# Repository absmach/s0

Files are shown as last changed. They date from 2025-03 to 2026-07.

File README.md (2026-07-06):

# 🔌 A0 Gateway

a0 is a modular **IoT gateway** built around the **ESP32-C6 (RISC-V)** platform, offering advanced wireless capabilities such as **Wi-Fi 6**, **Bluetooth 5**, and **802.15.4**. It supports multiple connectivity options including **NB-IoT/LTE-M** and optional **Ethernet**, enabling secure and scalable IoT deployments across **smart buildings**, **industrial environments**, and **city infrastructure**.

Optimized for **low-power, battery-powered operation** and modular expansion, A0 integrates **secure communication**, **local storage**, and multiple radio interfaces to serve as a versatile edge gateway in modern **IoT ecosystems**. While it includes support for **Wireless and Wired M-Bus**, its primary focus is on broad **IoT connectivity** and **interoperability**.

<p align="center">
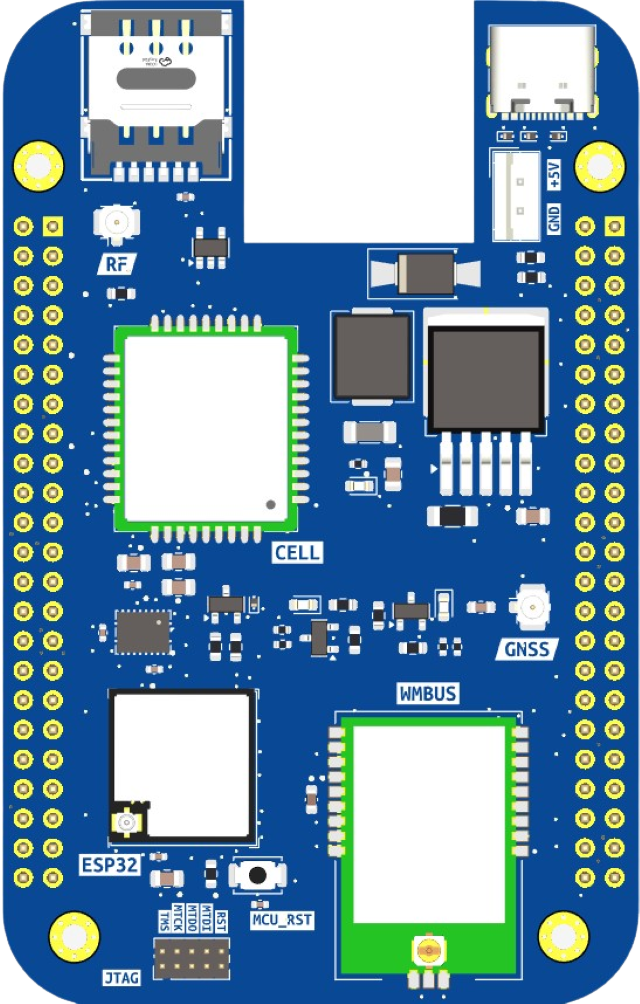
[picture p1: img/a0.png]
A0 Board
  
</p>

## 🌟 Features

- ⚙️ **RISC-V Architecture**: Powered by **ESP32-C6** with a RISC-V core for efficiency and flexibility.
- 📡 **Advanced Wireless Connectivity**: Supports **Wi-Fi 6**, **Bluetooth 5**, and **802.15.4** for robust IoT networking.
- 🌐 **Multiple Uplink Options**: Provides **NB-IoT/LTE-M** and optional **Ethernet** for reliable data transmission.
- 🔋 **Battery-Powered Operation**: Optimized for low-power deployments with long-lasting battery support.
- 🔐 **Advanced Security**: Includes **RSA-3072 secure boot**, **AES-128/256-XTS flash encryption**, **digital signature**, **HMAC identity protection**, and **hardware cryptographic accelerators** for performance. Built-in **Trusted Execution Environment (TEE)** ensures secure software separation.
- 🛠️ **Modular Design**: Optional Baseboard adds **Ethernet**, **Wired M-Bus**, and extra power options.
- 💾 **Local Storage**: Optional **microSD card** slot for logging and offline data buffering.
- 🔗 **Flexible IoT Connectivity**: Integrates with [**Magistrala**](https://github.com/absmach/magistrala) using multiple IoT protocols, including **MQTT**, **CoAP**, **HTTP**, and **WebSockets**.
- 🧩 **Zephyr RTOS Support**: Compatible with **Zephyr** for real-time, reliable IoT applications.
- 🖥️ **WebAssembly Runtime**: Runs lightweight, portable edge logic with **WAMR** (WebAssembly Micro Runtime).
- 🌀 **Propeller Orchestrator Integration**: Works with [**Propeller**](https://github.com/absmach/propeller) for secure, policy-driven orchestration of IoT workloads across the edge-cloud continuum.
- 📈 **Future-Ready for IoT Ecosystems**: Designed for interoperability in **smart buildings**, **industrial IoT**, and **city-scale deployments**.

## 🛠️ How It Works

1. **Connect & Collect**  
   Gather data from IoT sensors and devices via Wireless/Wired M-Bus, Wi-Fi, BLE, or IEEE 802.15.4.

2. **Process at the Edge**  
   Use the **ESP32-C6** for real-time processing or deploy **WebAssembly (Wasm)** modules with **WAMR** for flexible edge logic execution.

3. **Ensure Security**  
   Protect data and code integrity with **secure boot**, **flash encryption**, and **TEE-based isolation**, leveraging ESP32-C6 hardware security features.

4. **Transmit to IoT Platform**  
   Send processed data using **NB-IoT/LTE-M** or optional **Ethernet**, supporting multiple protocols (**MQTT**, **CoAP**, **HTTP**, **WebSockets**) for seamless integration with [**Magistrala**](https://github.com/absmach/magistrala).

5. **Orchestrate & Scale**  
   Integrate with the [**Propeller Orchestrator**](https://github.com/absmach/propeller) for policy-driven deployment and orchestration of workloads across the edge-cloud continuum.

6. **Manage Remotely**  
   Perform **OTA updates**, monitor device health, and manage configurations through connected IoT management tools.

## 📖 Documentation

For setup instructions, pinouts, and integration guides, see the full documentation:  
🔗 [A0 Documentation](https://www.absmach.eu/docs/hardware/s1-gateway/)

## 💡 Use Cases

- 🏢 **Smart Buildings**: Connect heat and water meters via Wireless M-Bus for real-time monitoring.
- 🏭 **Industrial IoT**: Collect and transmit sensor data in secure and bandwidth-constrained environments.
- 🌍 **Smart Cities**: Enable large-scale metering infrastructure with NB-IoT and LoRa connectivity.
- 🔐 **Secure Data Acquisition**: Ensure encrypted communication from edge devices to the cloud.

## 🔧 Hardware Highlights

- **Core Board**:

  - MCU: **ESP32-C6** (RISC-V architecture)
  - Connectivity: **Wi-Fi 6**, **Bluetooth 5**, **IEEE 802.15.4**, **Wireless M-Bus (RC-S2LP)**, **NB-IoT/LTE-M + GNSS (SIM7080G)**
  - Security: **Secure Boot**, **Flash Encryption**, **TEE**, Hardware Crypto Accelerators
  - Power: **USB-C**, 7.4 V battery, or Baseboard power supply

- **Baseboard**:
  - Ethernet: **W5500 controller**
  - Wired M-Bus: **TSS721A transceiver**
  - Storage: **microSD card slot**
  - Power: **24 V DC input**, battery charger

## 🤝 Contributing

Contributions are welcome! Please check the [CONTRIBUTING.md](#) for details on how to get started.

## 📜 License

A0 is licensed under the **Apache-2.0 License**. See the [LICENSE](LICENSE) file for more details.

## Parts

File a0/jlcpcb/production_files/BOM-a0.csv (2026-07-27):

Comment | Designator | Footprint | LCSC | Quantity
0.1uF | C10,C11,C4 | C_0805_2012Metric | C49678 | 3
10K | R1,R4,R5 | R_0805_2012Metric | C17414 | 3
10uF | C12,C13,C8,C9 | C_0805_2012Metric | C15850 | 4
1uF | C1,C2 | C_0805_2012Metric | C28323 | 2
2.2K | R2,R3 | R_0805_2012Metric | C17520 | 2
220 | R9 | R_0805_2012Metric_Pad1.20x1.40mm_HandSolder | C17557 | 1
220 | R11 | R_0603_1608Metric | C22962 | 1
22uF | C3 | C_0805_2012Metric | C45783 | 1
2k | R8 | R_0805_2012Metric_Pad1.20x1.40mm_HandSolder | C1359 | 1
330uF | C14 | C_Elec_8x10.2 | C74593 | 1
4.7uF | C5 | C_0805_2012Metric_Pad1.18x1.45mm_HandSolder | C6119904 | 1
40V 3A 550mV@3A Schottky | D1,D7,D8,D9 | D_SMA-SMB_Universal_Handsoldering | C8678 | 4
47uH/2A | L1 | L_Chilisin_BMRB00060624 | C5189938 | 1
5K1 | R6,R7 | R_0805_2012Metric | C27834 | 2
AMS1117-3.3 | U7,U8 | SOT-223-3_TabPin2 | C6186 | 2
BAT_JST_01x02 | J9 | JST_EH_B2B-EH-A_1x02_P2.50mm_Vertical | C20079 | 1
BZV55C27 | D5 | D_SMA | C688905 | 1
Beagle P8 | J5 | PinHeader_2x23_P2.54mm_Vertical | C725895 | 1
Beagle P9 | J6 | PinHeader_2x23_P2.54mm_Vertical | C725895 | 1
Conn_ARM_JTAG_SWD_10 | J10 | PinHeader_2x05_P1.27mm_Vertical | C2935953 | 1
ESD9B5.0ST5G | D2,D3,D4 | D_SOD-923 | C111566 | 3
ESP32 USB | J7 | USB_C_Receptacle_G-Switch_GT-USB-7010ASV | C2765186 | 1
ESP32-C6-MINI-1/U | U4 | XCVR_ESP32-C3-MINI-1U-N4 | C20627095 | 1
FerriteBead | FB1 | L_1206_3216Metric_Pad1.22x1.90mm_HandSolder | C668306 | 1
Fuse | F1 | Fuse_1206_3216Metric | C3105 | 1
LED | D10,D6 | LED_0603_1608Metric | C6848499 | 2
MCP73831-2-OT | U5 | SOT-23-5 | C14879 | 1
SMXS-02K-TP | U1 | C5439761 | C5439761 | 1
SMXS-08K-TP | SW5 | C5439767 | C5439767 | 1
SW_Push | SW1,SW2 | SW_Push_SPST_NO_Alps_SKRK | C720477 | 2
Screw_Terminal_01x02 | J8 | TerminalBlock_MaiXu_MX126-5.0-02P_1x02_P5.00mm | C8404 | 1
XL1509-5.0 | U6 | SOIC-8_3.9x4.9mm_P1.27mm | C61063 | 1
Conn_01x08 | J2 | PinSocket_1x08_P2.54mm_Vertical |  | 1
4.7uF | C6 | C_0805_2012Metric_Pad1.18x1.45mm_HandSolder |  | 1
Conn_01x08 | J4 | PinSocket_1x08_P2.54mm_Vertical |  | 1
10k | R10 | R_0805_2012Metric_Pad1.20x1.40mm_HandSolder |  | 1
Conn_01x08 | J3 | PinSocket_1x08_P2.54mm_Vertical |  | 1
Conn_01x08 | J1 | PinSocket_1x08_P2.54mm_Vertical |  | 1
4.7uF | C7 | C_0805_2012Metric_Pad1.18x1.45mm_HandSolder |  | 1

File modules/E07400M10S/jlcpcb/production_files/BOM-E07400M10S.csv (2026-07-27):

Comment | Designator | Footprint | LCSC | Quantity
0.1uF | C1 | C_0805_2012Metric | C49678 | 1
Conn_01x08 | J1,J2 | PinHeader_1x08_P2.54mm_Vertical | C492407 | 2
E07-400M10S | U1 | C2965513 | C2965513 | 1

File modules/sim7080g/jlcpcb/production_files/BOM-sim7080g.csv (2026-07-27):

Comment | Designator | Footprint | LCSC | Quantity
0.1uF | C1,C10,C11,C12,C13,C2,C5 | C_0805_2012Metric | C49678 | 7
100 | R12,R7 | R_0805_2012Metric | C17408 | 2
100uF | C9 | C_1206_3216Metric | C15008 | 1
10K | R1 | R_0805_2012Metric | C17414 | 1
10uF | C3 | C_0805_2012Metric | C15850 | 1
22 | R3,R4,R5 | R_0805_2012Metric | C17561 | 3
22pF | C6,C7,C8 | C_0805_2012Metric | C1804 | 3
4.7K | R2,R8,R9 | R_0805_2012Metric | C17673 | 3
47K | R10,R11,R6 | R_0805_2012Metric | C17713 | 3
Conn_01x08 | J2,J3 | PinHeader_1x08_P2.54mm_Vertical | C492407 | 2
Conn_Coaxial | J1,J4 | U.FL_Hirose_U.FL-R-SMT-1_Vertical | C88373 | 2
ESD9B5.0ST5G | D1,D5 | D_SOD-923 | C111566 | 2
ESDA6V1SC5 | D2 | SOT-23-5 | C2935146 | 1
LED | D3,D4 | LED_0805_2012Metric | C6848499 | 2
NANO SIM XG6P H1.35 | U3 | SIM-SMD_NANO-SIM | C7529386 | 1
NPN | Q1,Q2,Q3 | SOT-23 | C2150 | 3
SIM7080G | U2 | SIM7080G | C2943992 | 1
TXB0108RGY | U1 | Texas_RGY_R-PVQFN-N20_EP2.05x3.05mm | C194701 | 1

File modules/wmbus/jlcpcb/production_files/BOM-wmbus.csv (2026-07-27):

Comment | Designator | Footprint | LCSC | Quantity
0.1uF | C1 | C_0805_2012Metric | C49678 | 1
100 | R1 | R_0805_2012Metric | C17408 | 1
10K | R2 | R_0805_2012Metric | C17414 | 1
Conn_01x08 | J1,J2 | PinHeader_1x08_P2.54mm_Vertical | C492407 | 2
RC-S2LP-868 | U2 | RC-S2LP-868 | C37069913 | 1

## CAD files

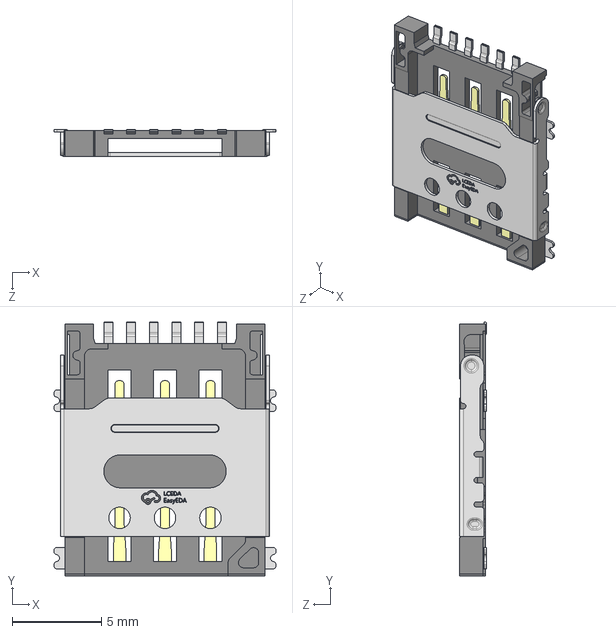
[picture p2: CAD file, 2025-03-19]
modules/sim7080g/modules/SIM-SMD_NANO-SIM.step
12.4 x 14.2 x 1.51 mm

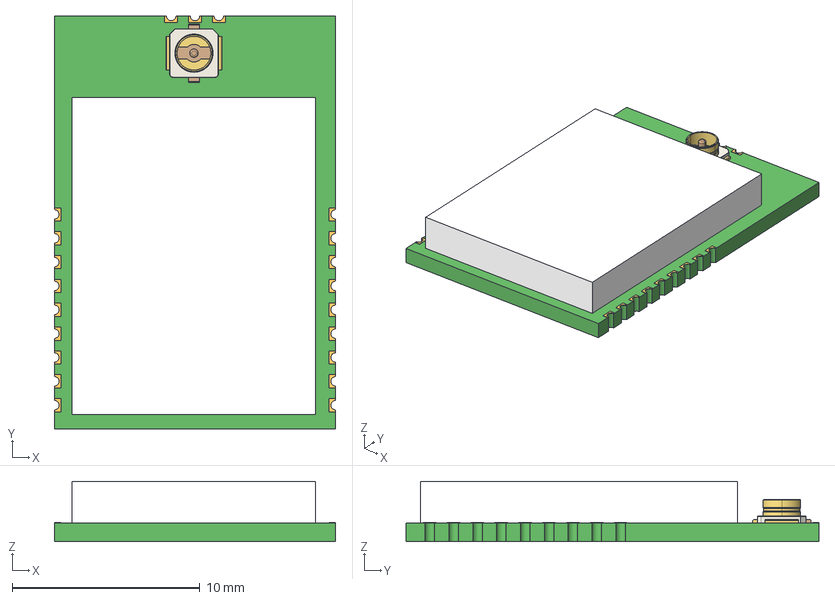
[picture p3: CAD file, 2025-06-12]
modules/wmbus/modules/RC-S2LP-868.stp
15.0 x 22.0 x 3.20 mm
BOARD
P x 9
P0
Z
MANIFOLD_SOLID_BREP_35968
MANIFOLD_SOLID_BREP_36563
MANIFOLD_SOLID_BREP_36971
MANIFOLD_SOLID_BREP_37634
MANIFOLD_SOLID_BREP_38050

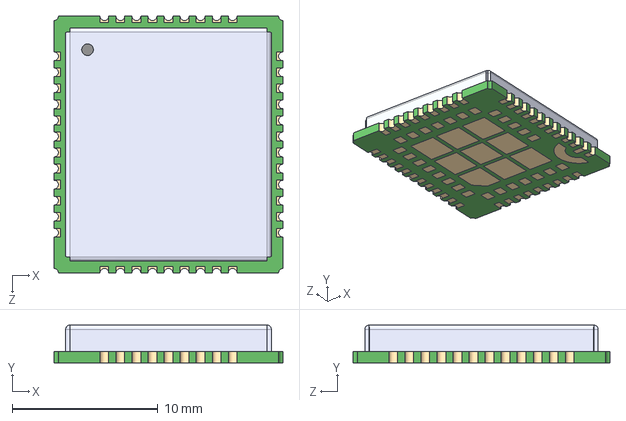
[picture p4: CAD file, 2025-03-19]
modules/sim7080g/modules/SIM7080G.step
15.7 x 2.60 x 17.6 mm

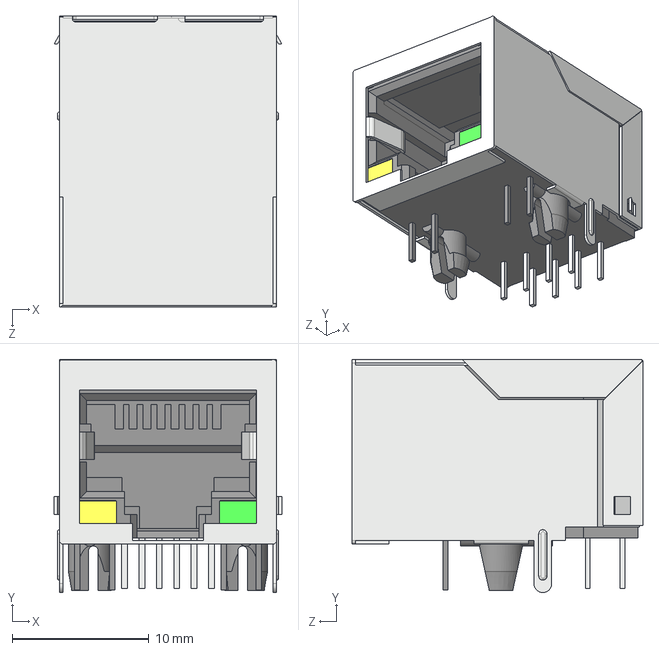
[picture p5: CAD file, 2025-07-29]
a0-base-board/modules/CRJ011-ML1-TH--3DModel-STEP-1.STEP
16.7 x 17.1 x 21.3 mm

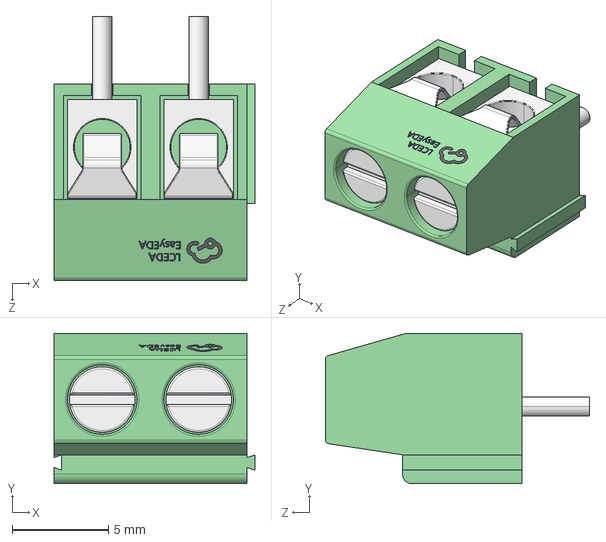
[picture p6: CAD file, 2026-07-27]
a0/modules/C8404.step
10.4 x 7.80 x 13.7 mm

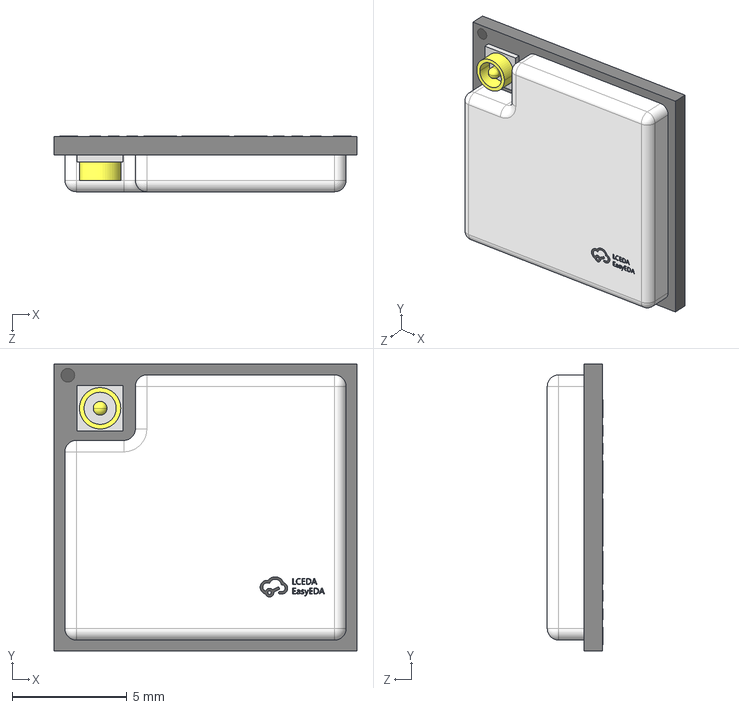
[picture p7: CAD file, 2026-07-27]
a0/modules/ESP32-C6-MINI-1U-H4.step
13.2 x 12.5 x 2.42 mm

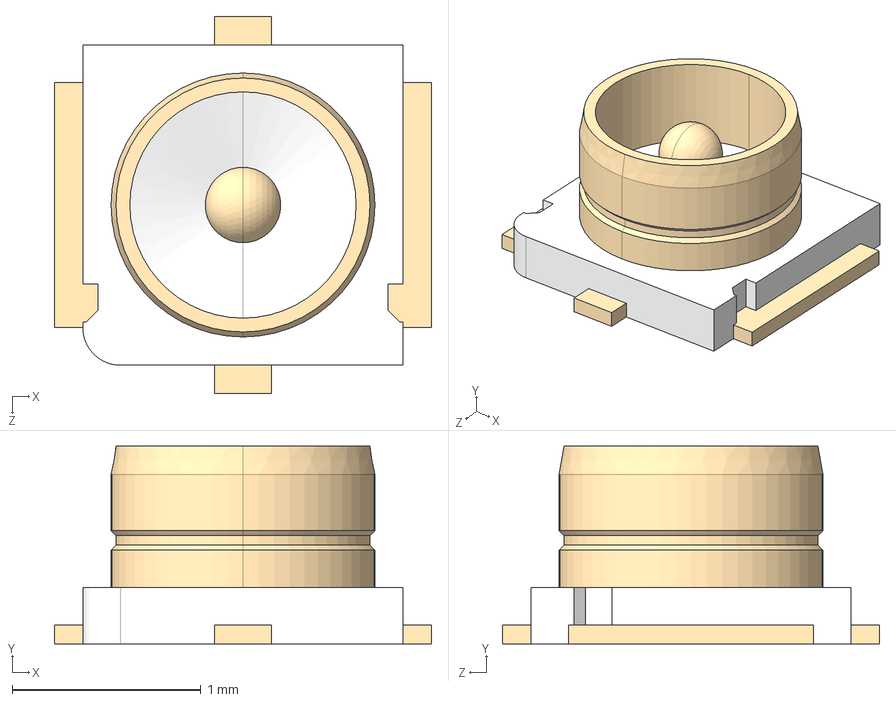
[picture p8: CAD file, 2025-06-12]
a0/modules/RSP-122811-02--3DModel-STEP-269445.STEP
2.00 x 1.05 x 2.00 mm

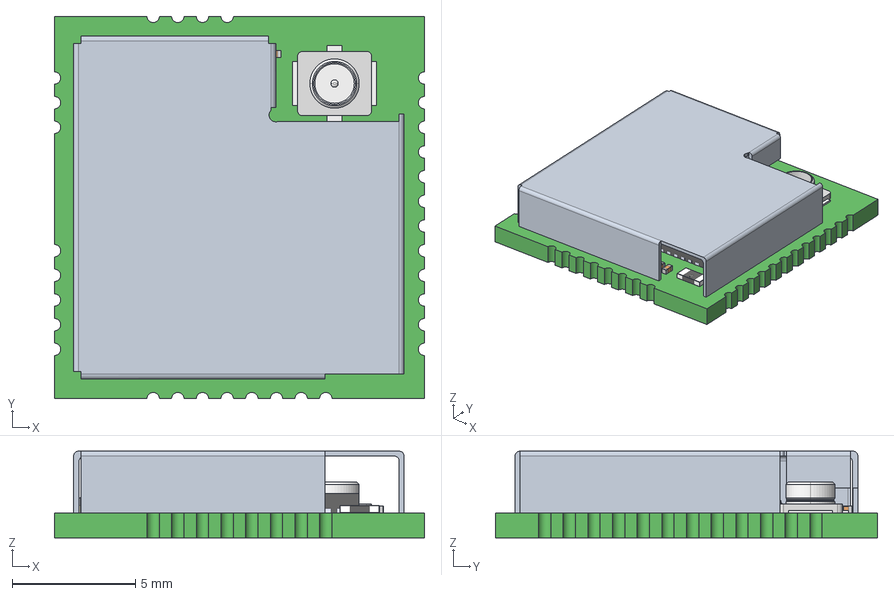
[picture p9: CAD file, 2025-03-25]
a0/modules/RAK3172--3DModel-STEP-100311.STEP
15.0 x 15.5 x 3.51 mm
0201_SMD_Capacitor x 36
Extruded
R0201 x 7
RES_1005-0402 x 3
QFN48_7x7
NT2016SA
C0402 x 4
crystal_rtf2012
D030A-そ敖裔

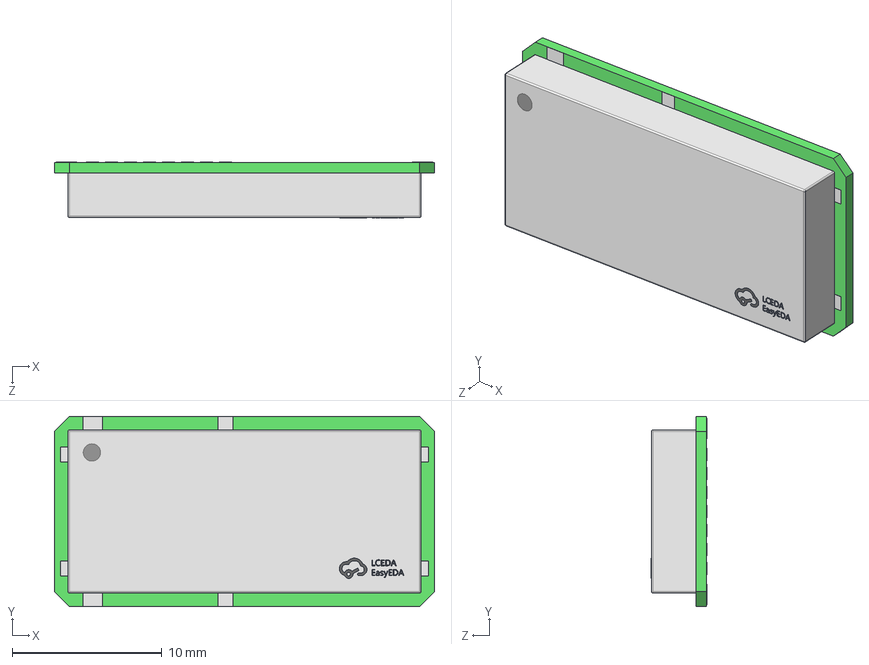
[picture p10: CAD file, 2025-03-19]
a0/modules/COMM-SMD_30P-L25.4-W12.7-P1.27_RC1180-MBUS3.step
25.4 x 12.7 x 3.72 mm

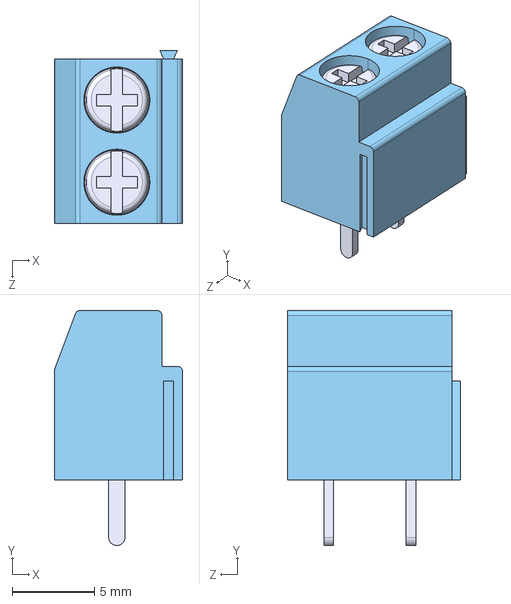
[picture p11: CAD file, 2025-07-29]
a0-base-board/modules/Blue_Screw_Terminal_3DModel-STEP-1.STEP
7.80 x 14.3 x 10.5 mm

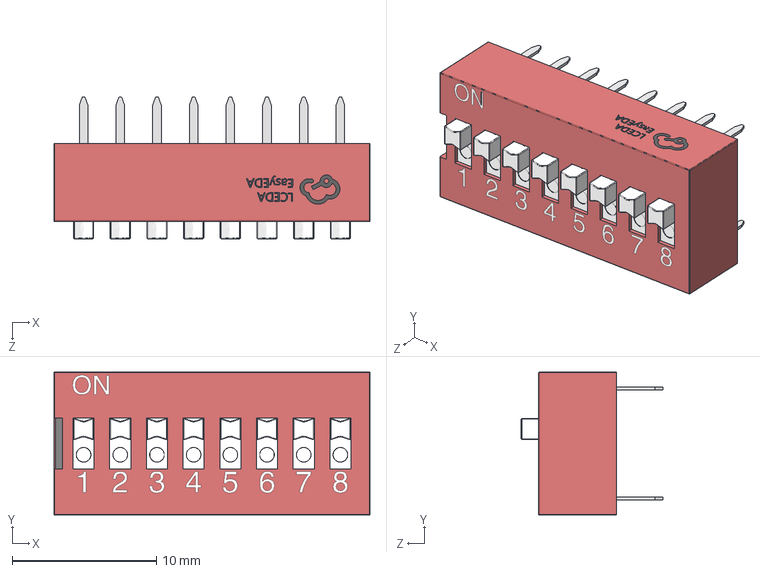
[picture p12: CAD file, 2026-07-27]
a0/modules/C99413.step
21.9 x 9.90 x 9.80 mm

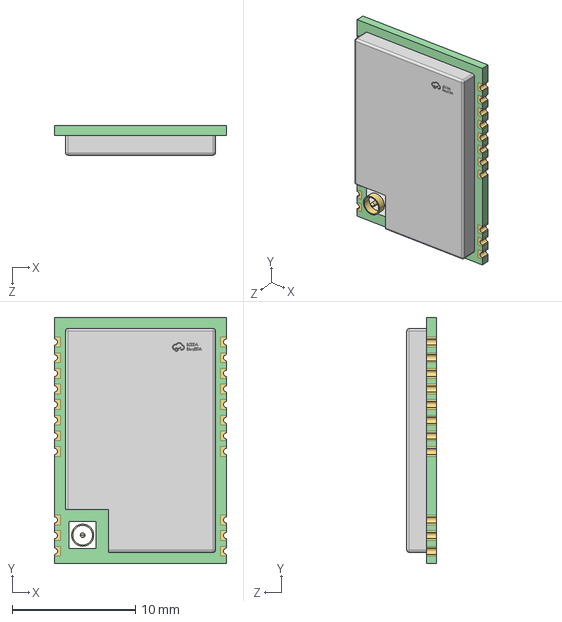
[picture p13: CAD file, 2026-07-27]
modules/E07400M10S/modules/C2965513.step
14.0 x 20.0 x 2.42 mm

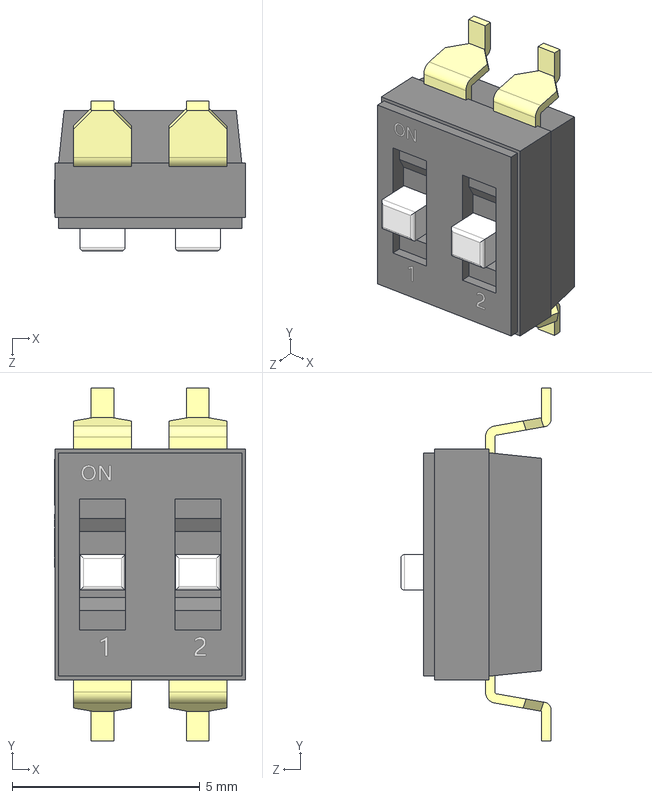
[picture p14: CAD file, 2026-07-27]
a0/modules/C5439761.step
5.09 x 9.40 x 4.00 mm

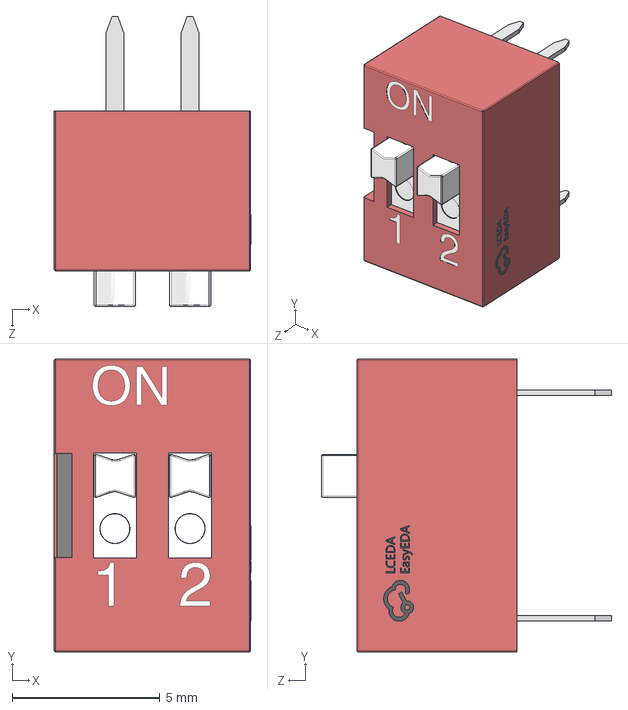
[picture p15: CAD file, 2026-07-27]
a0/modules/C99421.step
6.64 x 9.90 x 9.80 mm

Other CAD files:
a0-base-board/modules/FreeCADScrewterminal.step
a0/modules/C3293147.step
a0/modules/C5439767.step

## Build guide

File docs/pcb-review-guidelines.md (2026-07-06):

# PCB design review guide

This guide is formatted to be compatible with common markdownlint rules and can be used as a reusable PCB review checklist.

## Schematic validation: electrical design correctness

Validate the schematic before beginning layout work. Many PCB issues originate from schematic errors rather than routing.

### 1. Electrical rules check

- Run the ERC tool in your CAD platform to detect:

  - Unconnected pins
  - Incorrect pin types
  - Missing power flags
  - Structural issues

- Only ignore “not connected” warnings when the pin is purposefully marked as not connected.
- Confirm all IC power pins are connected.

### 2. Pinout and footprint orientation review

A common source of design failure is incorrect footprint orientation.

Frequent issues include:

- Pin 1 mismatch between schematic and footprint
- Mirrored connectors
- Incorrect transistor or MOSFET pinouts
- Using the wrong footprint library entry

Visually verify the orientation of each footprint against the component datasheet.

### 3. Power path and load analysis

Confirm all power rails and devices are adequately sized.

Checklist:

- Estimate maximum current draw for the whole board and for each rail
- Validate regulator headroom for voltage and current
- Check diode polarity and ratings
- Confirm power sequencing where required

Always consider worst case environmental and load conditions.

---

### 4. Safety and protection components

Confirm appropriate protection measures exist:

- ESD protection on external interfaces
- Series resistors on sensitive signals
- Fuses or resettable protection on external power inputs
- Input filtering and surge suppression on noisy or exposed rails

### 5. Stackup and impedance planning

This is important for high speed or RF designs.

Verify:

- Trace widths and spacing for controlled impedance lines
- Via sizes and types suitable for the stackup
- Clean and continuous return paths under high speed traces

Use tools such as Saturn PCB Toolkit and your manufacturer’s stackup data.
If unsure, start from your manufacturer’s default four layer stackup.

### 6. Mechanical and 3D fit verification

Import the board into a 3D tool to detect:

- Height conflicts with enclosures or other boards
- Misaligned connectors relative to panel cut outs
- Incorrect button and mechanical placements
- Blocked or mislocated mounting holes

When uncertain, print the PCB outline at one to one scale and place it in the enclosure to validate the fit.

## Layout and routing review

### 7. Physical footprint validation (paper test)

If possible, print the PCB at one to one scale and place the actual components on it.

This helps expose:

- Footprint errors
- Incorrect spacing
- Mechanical interference
- Misalignment of connectors and buttons

### 8. Design rules check during layout

Run design rules checks frequently rather than only at the end.

Configure and verify:

- Minimum clearance and additional safety margin where needed
- Via, annular ring and hole size settings
- Constraints and classes for high speed signals and special nets

The board should reach zero design rules errors before generating manufacturing files.

### 9. Power and ground integrity review

Inspect highlighted power nets and ground planes.

Check for:

- Undersized traces on power nets
- Long or broken return paths
- Ground plane gaps under high speed or sensitive lines
- Insufficient stitching vias between ground planes
- Potential thermal bottlenecks on high current devices

### 10. High speed signal routing checks

Verify the fundamentals:

- Apply length matching for differential pairs where required
- Maintain consistent spacing and reference planes
- Prefer 45 degree or gentle routing over sharp angles
- Avoid routing over ground plane gaps or splits
- Keep clock lines short and well referenced to ground
- Separate noisy digital lines from sensitive analog circuits

## Manufacturing output verification

Ensure the exported files accurately represent the intended design.

### 11. External Gerber verification

Use an external viewer to review:

- Pad to drill alignment and hole positions
- Board outline and any internal cutouts
- Silkscreen clearance from pads and solder mask openings
- Text orientation and polarity on all layers

Zoom in significantly to catch subtle alignment and clearance issues.

## Final human review: checks tools cannot perform

These items frequently escape automated checks and require manual inspection.

### 12. Common errors to review

#### 12.1 Connectivity and orientation

- Swapped receive and transmit signals
- Reversed MOSFETs, diodes and LEDs
- Incorrect connector pin orientation
- Inconsistent pin numbering between schematic and layout

#### 12.2 Power integrity

- Missing bulk capacitors near major loads
- Regulator thermal issues and insufficient copper area
- Missing ground pours in key areas
- Incorrect placement or use of ferrite beads

#### 12.3 Analog and mixed signal

- Long analog paths routed near switching regulators or digital clocks
- Improper filtering or layout on ADC references
- Sensitive nodes crossing splits or noisy ground returns

#### 12.4 Digital design

- Missing pull ups or pull downs for buses such as I2C
- Floating reset or boot mode pins
- Overloaded or heavily shared GPIOs

#### 12.5 RF and wireless

- Incorrect antenna placement relative to ground and enclosure
- Inadequate ground clearance under or around antennas
- Failure to follow manufacturer layout guidelines and keep out zones
- Ground cuts or copper near antenna areas where they should be clear

#### 12.6 Manufacturability and assembly

- Silkscreen covering pads or solder mask openings
- Missing global or local fiducials
- Lack of test pads for key signals and rails
- Components placed too close, increasing risk of solder defects
- Via in pad without filling or capping where it can cause solder wicking

#### 12.7 Mechanical checks

- Misaligned connectors and buttons relative to enclosure features
- Incorrect battery holder orientation and polarity marking
- Mounting hole clearance issues and interference with hardware
- Keep out violations around mounting hardware and edges

## Pre submission checklist

Confirm the following before sending the design to fabrication:

1. The board can be assembled by hand if necessary.
2. All polarized components are clearly indicated and oriented.
3. PCB and connector orientations have been double checked.
4. Critical test points are accessible for probing.
5. A debugging and bring up plan exists for the first prototypes.

Any answer of “no” to these points requires correction before submission.

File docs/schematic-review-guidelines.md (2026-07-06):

# Schematic review guideline

## 1. Review process

### 1.1 Before you open the schematic

Clarify the context before you comment on anything.

- Understand the product

  - What is the device or system supposed to do
  - Target environment (lab, industrial, outdoor, automotive)
  - Expected lifetime and reliability level

- Capture key electrical constraints

  - Input power range and type (for example 12–24 V DC, USB, PoE, mains)
  - Power budget for each rail and overall current limits
  - Safety or isolation requirements
  - Compliance targets (EMC, safety, surge, ESD)

- Gather reference material

  - Datasheets for all major ICs
  - Vendor reference designs and evaluation board schematics
  - System block diagram or architecture document

If any of these are missing, note this as a process issue before deep review.

### 1.2 First pass overview

Goal: understand the big picture and find obvious show-stoppers.

- Identify major blocks

  - Power input and protection
  - Power regulation and sequencing
  - MCU, SoC or FPGA section
  - Memories
  - Communication interfaces
  - Sensors and analog front ends
  - Drivers and actuators
  - Connectors and external interfaces
  - Test and debug interfaces

- Check basic connectivity

  - Every block should have a power source
  - No use of rails that do not exist anywhere
  - Key interfaces clearly connected between blocks

- Look for immediate red flags

  - MCUs or ICs with no supply or missing ground pins
  - Devices with no decoupling capacitors
  - No obvious way to program or debug the main controller
  - Nets with names that suggest “TODO” or “TBD” on critical signals

Do not worry about component values yet. Focus on structure and intent.

### 1.3 Structure and readability pass

Goal: confirm the schematic is readable and maintainable.

- Sheet organization

  - Group related circuits into separate sheets per function
  - Use clear sheet titles such as “PWR_12V_IN”, “MCU_CORE”, “SENSORS”

- Net naming strategy

  - Use consistent names for power rails (for example 12V, 5V0, 3V3, VBAT)
  - Use clear names for clocks, resets and boot signals
  - For differential pairs, use P and N suffixes consistently
  - Avoid leaving important nets with auto-generated names

- Symbol and library consistency

  - Same part type uses the same symbol everywhere
  - Power pins are either visible on the symbol or handled consistently on a dedicated page
  - Pin numbers and pin names match the datasheet

Ask yourself whether someone else could understand the design in less than thirty minutes.

### 1.4 Detailed functional review

Process for the deep technical review:

- Review block by block using the technical checklists in section 2
- For each block

  - Compare against datasheets and reference designs
  - Check operating conditions, absolute maximum ratings and margins
  - Consider normal operation, start-up and fault conditions
  - Note any unclear design intent or missing comments

Typical order for the detailed pass:

1. Power input and protection
2. Power conversion and rails
3. Decoupling and grounding
4. MCU or main controller (including clock and reset)
5. Memories
6. High speed interfaces
7. Analog and sensor circuits
8. Drivers and actuators
9. Connectors and external I or O
10. Test, debug, safety and EMC

### 1.5 System level “what if” pass

After the detailed review, do a scenario based sweep.

- Power and faults

  - What happens if the input is reversed
  - What happens if the input voltage is too high or too low
  - What happens during brownouts or fast power cycling

- Cables and environment

  - What happens if external cables are long and noisy
  - What happens during ESD events on connectors
  - What happens if connectors are partially inserted

- Firmware and behavior

  - Can the device still be programmed if firmware is bad
  - Are boot mode and recovery paths available on the final product

- Maintenance and service

  - Can a technician probe key rails and signals easily
  - Are errors recoverable without rework

Record any issues or questions that come out of these scenarios.

## 2. Technical checklists

### 2.1 Power input and protection

Goals: correct operating range, protection against common faults and basic EMC robustness.

- Input range and polarity

  - Confirm components on the input path are rated for maximum expected voltage plus margin
  - Provide reverse polarity protection for field wiring where mis-wiring is likely
  - Include overvoltage protection such as TVS diodes or clamps as appropriate

- Inrush and current limiting

  - Consider inrush current caused by large bulk capacitors
  - Use fuses or resettable protection with the correct current and breaking capacity

- EMI and surge protection

  - Add common mode chokes or LC filters for long cable runs when needed
  - Add surge protection devices for interfaces exposed to harsh environments

Common mistakes:

- No reverse polarity protection on user accessible power connectors
- TVS diode rated for insufficient power or incorrect standoff voltage
- Components on the input rated only slightly above nominal voltage with no margin

### 2.2 Power regulation and rails

For each regulator (buck, boost, buck-boost, LDO):

- Topology and connections

  - Verify all pins match the datasheet typical application circuit
  - Check feedback network values and desired output voltage
  - Check enable, power good and soft start pins where available

- Passive components

  - Input and output capacitors meet value, voltage rating and ESR requirements
  - Inductors meet inductance, current rating and saturation current requirements
  - Sense resistors and compensation components are present and sized correctly

- Current and thermal considerations

  - Regulator maximum current significantly exceeds maximum load current
  - Worst case power dissipation is within safe limits with margin
  - Heat dissipation and copper area on the PCB are considered in the design

- Power sequencing

  - Verify required power up order for core, IO and analog domains
  - Ensure enable and reset pins enforce proper sequencing where needed

Typical error patterns:

- Trying to drop a large voltage across a small LDO at high current
- Using “typical” capacitor values but ignoring ESR and derating
- Forgetting to handle power up order for complex ICs that require it

### 2.3 Decoupling and bypassing

Decoupling is essential for stability and noise control.

- Per IC

  - Place at least one small ceramic capacitor close to each power pin
  - Include a local bulk capacitor on each rail feeding a group of ICs

- Important rails

  - Follow vendor recommendations for decoupling count and placement on MCUs, FPGAs and SoCs
  - Provide separate or filtered decoupling for analog reference and analog supply pins when specified

- Ground return

  - Ensure each decoupling capacitor connects directly between the power pin and its local ground reference
  - Avoid routing decoupling returns through narrow or long ground paths

Common mistakes:

- Missing small local capacitors on some power pins of a large IC
- Relying only on one or two larger capacitors far away from the IC
- Sharing decoupling components between unrelated functional blocks

### 2.4 Grounding and reference strategy

- Ground topology

  - Use a continuous ground plane for most digital designs
  - In mixed signal designs, keep noisy and quiet sections separated but joined at a controlled point

- High current paths

  - Separate high current and switching returns from sensitive analog returns
  - Keep motor or load currents out of the ground area under ADCs and precision circuitry

- Connectors and shielding

  - Decide how cable shields are terminated (chassis, RC network, ferrite bead)
  - Avoid routing cable shield currents through signal reference grounds

Red flags:

- Multiple ground symbols without clear documentation of their relationship
- High current load returns routed through the same narrow trace as MCU ground

### 2.5 Clocks and crystals

- Crystal based clocks

  - Verify connection of crystal pins to the correct MCU or IC pins
  - Size load capacitors according to the crystal load capacitance and datasheet formulas
  - Add series resistance if recommended by the vendor

- Oscillator modules

  - Confirm supply decoupling for oscillator modules
  - Ensure output format and voltage are compatible with the clock input

- Clock tree

  - Check main system clock frequency versus maximum rated frequency
  - Confirm any derived clocks are within valid ranges

Typical mistakes:

- Using approximate capacitor values instead of calculated ones
- Leaving crystal load capacitors out, assuming the MCU will still start
- Forgetting supply decoupling on clock modules

### 2.6 Reset and boot configuration

- Reset circuits

  - Provide a defined reset with a pull up or pull down as required
  - Consider supervisor or power on reset ICs in designs with slow or noisy supplies
  - Connect reset buttons safely and consider simple debounce if required

- Boot and configuration pins

  - Tie boot mode pins to defined logic levels with resistors
  - Ensure that any shared boot and GPIO pins have biasing compatible with both functions
  - Provide a method to force bootloader or recovery mode in production

- Recovery paths

  - Confirm there is a way to reflash or rescue devices with bad firmware without physical rework

Common mistakes:

- Leaving boot configuration pins floating
- Driving boot pins directly from other logic without reliable pull devices
- No way to enter a bootloader except through application firmware

### 2.7 MCU, SoC or FPGA section

- Power and decoupling

  - All power pins are connected to the correct rails
  - All ground pins are connected and exposed pad is tied correctly
  - Decoupling follows vendor guidelines

- Special pins

  - Analog and reference pins are treated according to the datasheet
  - Clock and oscillator pins are wired correctly

- Debug and program interfaces

  - JTAG, SWD or equivalent debug pins are accessible on a connector or pads
  - Any required mode pins for debugging are available

- GPIO assignments and limits

  - No pin is overloaded beyond its current capability
  - Total current per port and per device is within limits
  - Pins used for analog inputs are not shared with heavy digital loads

Typical issues:

- Exposed thermal pad not tied to ground or tied incorrectly
- Using strapping or boot pins as general IO without understanding reset behavior
- Leaving critical debug pins inaccessible in the final assembly

### 2.8 Memories

- Power and decoupling

  - Each memory IC has appropriate supply decoupling

- Interface wiring

  - For SPI memories, verify MOSI, MISO, SCK and chip select orientation and naming
  - For parallel or high speed memories, check every address, data and control pin mapping
  - For QSPI or similar interfaces, ensure data lines are correctly numbered

- Pull ups and terminations

  - I2C memories have appropriate pull up resistors on SCL and SDA
  - Required termination or bias networks for high speed memory are included

- Multiple devices on a bus

  - Each device has its own chip select
  - No floating chip select pins

Common problems:

- Swapping MOSI and MISO because of naming differences between IC and MCU
- Forgetting pull up resistors on I2C buses
- Leaving unused address or configuration pins floating

### 2.9 Communication interfaces

#### 2.9.1 USB

- Topology

  - Confirm correct connector type and pin mapping
  - Ensure D plus and D minus are not swapped

- Protection

  - ESD protection near the connector on data and VBUS
  - Overcurrent protection on host ports

- Power and detection

  - VBUS detection signals wired correctly where required
  - Power switching follows USB specifications if the device can source power

#### 2.9.2 Ethernet

- PHY and magnetics

  - Verify all pairs match the reference design pinout
  - Check center tap connections and biasing resistors

- Clocking

  - Confirm crystal or oscillator values and load components for the PHY

- Protection

  - Include ESD and surge protection where needed
  - Confirm common mode chokes and filters are used per reference design

#### 2.9.3 UART, RS-485, CAN, I2C and SPI

- Signal levels

  - Ensure level shifting where voltage domains differ

- Bus management

  - Provide pull ups on I2C
  - Provide termination and biasing for RS-485 and CAN as appropriate

- Direction control

  - Correctly drive direction and enable pins on transceivers

- Shared buses

  - Each peripheral has a unique chip select or address
  - Consider mixed mode compatibility when multiple devices share one bus

### 2.10 Analog and sensors

- Input ranges

  - Ensure sensor outputs and analog signals stay within ADC or amplifier limits
  - Provide scaling or level shifting where needed

- Filtering

  - Add appropriate RC or active filters for noisy signals and anti aliasing where necessary

- References and grounds

  - Provide stable reference voltages and follow decoupling recommendations
  - Keep analog ground and reference paths clean and away from switching currents

- Protection

  - Add series resistors and clamps for external or field connected analog inputs
  - Use ESD protection for sensor connectors exposed to users

Common issues:

- Connecting external sensors directly to MCU pins without any protection
- Ignoring sensor output impedance when designing ADC input filters
- Placing sensitive analog circuits near noisy digital or power sections

### 2.11 Drivers and loads

- Driver selection

  - Verify MOSFET and driver choice suits voltage, current and speed requirements
  - Confirm gate drive voltage is sufficient for required Rds(on)

- Protection

  - Provide flyback diodes for inductive loads
  - Use snubbers or clamps to manage switching edges if required

- Power and thermal

  - Confirm voltage, current and power ratings with sufficient margin
  - Check thermal dissipation paths and package capability

- Control interfaces

  - Ensure MCUs are not driving heavy loads directly without drivers
  - Use appropriate gate resistors and pull downs

Common mistakes:

- No flyback paths for inductive loads such as relays and motors
- Overstressing MCU pins by using them directly on high current loads
- Underestimating MOSFET or driver heat dissipation

### 2.12 Connectors and external IO

- Pinouts

  - Provide clear pin names on the connector symbol
  - Confirm pin order against mechanical drawings or cable specs

- Power and polarity

  - Make reversed connections unlikely with keyed connectors when feasible
  - Add protection where mis-wiring is possible

- Protection and robustness

  - Use ESD and surge protection on user accessible connectors
  - Add series resistors or filters on long signal lines

### 2.13 Test and debug features

- Debug access

  - Expose programming and debug interfaces on connectors or pads
  - Ensure access in the assembled product or test jigs

- Test points

  - Add test points for each power rail
  - Add test points for reset, clocks and key communication signals
  - Provide at least one easy ground reference test point

- Production and service

  - Mark do not populate components clearly where used
  - Provide alternate power entry for lab testing when useful

### 2.14 Safety, isolation and EMC

- Isolation

  - Maintain clear separation between high and low voltage domains
  - Use isolation components correctly powered on both sides

- Creepage and clearance

  - Ensure PCB layout can meet required creepage and clearance distances
  - Reflect isolation boundaries clearly in the schematic

- Surge, ESD and EFT protection

  - Include appropriate protection parts on mains and long external links
  - Consider common mode chokes, filters and RC snubbers for EMC

## 3. Tools and techniques for review

### 3.1 Using features in the EDA tool

- Net highlighting

  - Trace important nets such as power rails, resets, clocks and communication buses

- Cross probing

  - When layout is available, cross probe between schematic and PCB

- Automated checks

  - Run electrical rules checks to find unconnected pins and multi drivers
  - Run design rule checks on the PCB when available to find simple connection errors

Treat ERC and DRC as helpers, not as replacements for manual thinking.

### 3.2 Datasheet and reference comparison

- Place the datasheet and schematic side by side
- For each critical IC

  - Compare pin by pin with the typical application circuit
  - Confirm presence of all required support components
  - Check recommended operating conditions and margins

### 3.3 Bill of materials and netlist checks

- Bill of materials review

  - Verify capacitor and diode voltage ratings against rail voltages
  - Verify resistor power ratings where high dissipation is expected

- Netlist review

  - Look for multiple net names that should be one rail due to spelling differences
  - Confirm all intended power rails are present and consistently named

## 4. Recording and communicating feedback

### 4.1 Comment format

Use a structured format so issues are easy to track.

- Assign an identifier such as “PWR-01” or “MCU-03”
- Specify the location

  - Sheet name
  - Reference designator
  - Net name

- Describe the issue briefly
- Explain impact
- Suggest a fix or request clarification

Example:

- Identifier

  - MCU-02

- Location

  - Sheet “MCU_CORE”
  - U3 boot configuration pin

- Issue

  - Boot pin left floating

- Impact

  - Boot mode may be unpredictable and cause start up failures

- Suggestion

  - Add a pull down resistor to ground according to the datasheet and provide a way to override if needed

### 4.2 Prioritizing issues

Not all issues are equal. Mark them clearly.

- Blocker

  - Must be fixed before proceeding
  - Safety issues or high likelihood of complete failure

- High

  - Significant functional risk or reliability concern

- Medium

  - Recommended for robustness, noise margin or clarity

- Low

  - Style, readability or minor cleanup

### 4.3 Reviewing your own design

If you are both designer and reviewer, try to combat familiarity.

- Take a break between design and review
- Use this guideline as a checklist and actively try to find faults
- Ask “how could this fail in the field” and trace those scenarios

## 5. Practical review sequence

You can follow this sequence during an actual review.

1. Read the product description and constraints
2. Scan the schematic for major blocks and overall signal flow
3. Review power input and protection
4. Review power regulators and derived rails
5. Check decoupling and ground strategy across all sheets
6. Deep review of MCU or main controller including clock, reset and boot pins
7. Review memories and their interfaces
8. Review communication interfaces
9. Review analog and sensor circuits
10. Review drivers and loads
11. Review connectors and external IO
12. Review test, debug, safety and EMC aspects
13. Run ERC and DRC, check BoM and do a final system level “what if” pass

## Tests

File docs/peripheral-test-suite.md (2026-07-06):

# A0 and Baseboard Peripheral Testing Suite

This document contains all electrical and functional tests required to validate the A0 module and its baseboard after PCB fabrication.

## 1. Visual and continuity checks

### 1.1 Visual inspection

- [ ] All connectors aligned (USB-C, RJ45, terminal blocks)
- [ ] No solder bridges on ESP32-C6, SIM7080G, W5500, S2LP
- [ ] No missing components on regulator networks
- [ ] No polarity errors on diodes, LEDs, electrolytic caps
- [ ] No cracked MLCCs or lifted pads

### 1.2 Continuity tests

- [ ] 3V3 ↔ GND not shorted
- [ ] **1V8 ↔ GND not shorted**
- [ ] 5V ↔ GND not shorted
- [ ] Battery input ↔ GND high resistance
- [ ] No unexpected continuity between high-current nets

## 2. Power-up and rail validation

### 2.1 A0 USB-C power

- [ ] 5 V measured at TP1 ≈ 5.0 V
- [ ] 3.3 V measured at TP3 ≈ 3.3 V
- [ ] No components overheating
- [ ] USB enumeration visible on PC

### 2.2 A0 battery input power

- [ ] 7.0 V applied correctly to JST battery input
- [ ] 3.3 V rail stable
- [ ] Idle current within expected range
- [ ] No thermal hotspots

### 2.3 Baseboard power (no A0 installed)

- [ ] TP1 = 3.3 V
- [ ] TP2 = 5 V
- [ ] TP3 = GND
- [ ] Regulators warm but not hot

### 2.4 A0 powered from baseboard

- [ ] A0 boots normally from baseboard input
- [ ] USB log available
- [ ] No resets or brownouts

## 3. ESP32-C6 core bring-up

### 3.1 USB console

- [ ] Boot messages observed at 115200 baud
- [ ] No continuous reboot loop

### 3.2 Flash bring-up firmware

- [ ] Flashing successful via USB
- [ ] LED blinks according to firmware
- [ ] UART prints periodic heartbeat

### 3.3 JTAG scan

- [ ] MTCK / MTMS / MTDI / MTDO connected
- [ ] JTAG probe detects single ESP32-C6
- [ ] No unstable connection

## 4. A0 onboard peripheral tests

### 4.1 GPIO and LED

- [ ] EXT_GPIO1 toggles normally
- [ ] EXT_GPIO2 toggles normally
- [ ] EXT_GPIO3 toggles normally
- [ ] LED pin toggles observable

### 4.2 I2C test

- [ ] Bus scan detects connected device
- [ ] No SDA/SCL stuck low
- [ ] Clean SCL/SDA waveforms

### 4.3 SPI test

- [ ] MOSI/MISO/SCK functional
- [ ] Loopback or flash readback correct
- [ ] Clean 1–4 MHz clock waveform

### 4.4 SIM7080G tests

#### Power control

- [ ] SIM7080_PWR toggles modem on/off
- [ ] Current draw changes appropriately

#### UART AT-link

- [ ] “AT” returns “OK”
- [ ] “ATI” returns modem info
- [ ] “AT+CSQ” returns valid RSSI

#### Network attach

- [ ] APN configured
- [ ] Attach success
- [ ] GNSS valid (outdoors)

### 4.5 Wireless M-Bus (S2LP)

- [ ] Driver initializes
- [ ] Transmit test packet successful
- [ ] Remote receiver or RF tool detects frame

### 4.6 USB-C stability

- [ ] Device enumerates
- [ ] High-rate serial spam test stable
- [ ] No disconnects

## 5. Baseboard peripheral tests

### 5.1 SPI link between A0 and baseboard

- [ ] Baseboard SPI activity visible
- [ ] No contention or stuck lines

### 5.2 Ethernet (W5500)

- [ ] PHY reset functional
- [ ] DHCP or static IP obtained
- [ ] Ping success
- [ ] TCP transfer stable

### 5.3 SD card slot

- [ ] SD card detected
- [ ] Filesystem mount OK
- [ ] Read/write/delete cycle successful

### 5.4 Wired M-Bus

- [ ] TXI/RXI waveforms correct
- [ ] Request frames sent
- [ ] Meter responds

### 5.5 Rail robustness

- [ ] 3V3 holds under 100 mA added load
- [ ] No thermal runaway

## 6. System-level tests

### 6.1 End-to-end data path

- [ ] Read sensor or M-Bus input
- [ ] ESP32 processes packet
- [ ] Data forwarded via NB-IoT or Ethernet
- [ ] Backend receives correct data

### 6.2 Sleep modes

- [ ] Light sleep reachable
- [ ] Deep sleep current matches datasheet values
- [ ] Wake reliably from GPIO/RTC

### 6.3 Long-run soak test (24–72 hours)

- [ ] SD card logging stable
- [ ] Ethernet or NB-IoT heartbeat stable
- [ ] No memory leaks or crashes
- [ ] No unexplained resets

## ESP32-C6 Bring-Up Firmware Template (ESP-IDF)

This firmware template is used to validate all electrical and functional subsystems of the A0 module and its baseboard. It must be compiled with the official Espressif toolchain.

### **Build Framework / Toolchain Requirements**

**Framework:**

- ESP-IDF (Espressif IoT Development Framework), version **5.x or later**

**Compiler Toolchain:**

- Xtensa-ESP32-C6 GCC toolchain (installed automatically by ESP-IDF)

**Why ESP-IDF is required:**

- Uses native FreeRTOS integration
- Uses ESP-IDF drivers for GPIO, UART, SPI, I2C
- Uses ESP logging system (`esp_log.h`)
- Uses ESP-IDF startup & build system (CMake)
- Arduino Core is **NOT compatible** with this code

### **Install ESP-IDF**

Follow Espressif’s official guide for ESP32-C6:

```bash
git clone -b v5.2 https://github.com/espressif/esp-idf.git
cd esp-idf
./install.sh esp32c6
```

### **Export Environment**

Before building:

```bash
. $HOME/esp/esp-idf/export.sh
```

This sets the PATH, compiler toolchain, and IDF environment variables.

### **Recommended Project Structure**

```shell
firmware/
│
├── CMakeLists.txt
├── sdkconfig
└── main/
    ├── CMakeLists.txt
    └── main.c     ← place bring-up firmware here
```

**Top-level CMakeLists.txt:**

```cmake
cmake_minimum_required(VERSION 3.16)
include($ENV{IDF_PATH}/tools/cmake/project.cmake)
project(a0_bringup)
```

**main/CMakeLists.txt:**

```cmake
idf_component_register(SRCS "main.c" INCLUDE_DIRS ".")
```

This is all you need to compile the provided bring-up code.

### **Build Firmware**

Inside the project folder:

```bash
idf.py build
```

### **Flash Firmware**

Replace `/dev/ttyACM0` with the correct USB device:

```bash
idf.py -p /dev/ttyACM0 flash
```

### **Flash + Monitor**

```bash
idf.py -p /dev/ttyACM0 flash monitor
```

Exit monitor with:
`Ctrl + ]`

### **Serial Console Use**

The firmware accepts commands over **UART0** (USB CDC), running at **115200 baud**.

Commands:

| Command | Description |
| --- | --- |
| `LIST` | Prints all test names |
| `RUN ALL` | Runs the entire test suite |
| `RUN <NAME>` | Runs a specific test |
| Any invalid command | Returns JSON error |

### **Output Format**

Each test prints structured JSON:

```json
{ "type": "result", "name": "W5500_BASIC", "result": "PASS" }
```

This enables automated factory testing and Python integration.

### **Additional Instructions**

1. Flash the firmware using:

   ```bash
   idf.py -p /dev/ttyACM0 flash monitor
   ```

2. Open the USB serial console at **115200 baud**.
3. Issue commands:

   - `LIST`
   - `RUN ALL`
   - `RUN MODEM_AT`

4. All results are printed as JSON for easy machine parsing.

Below is a minimal and clean template suitable for executing all tests above. You can drop this straight into `main.c` and adapt pin mappings and actual driver code as needed.

```c
#include <string.h>
#include <stdio.h>

#include "driver/gpio.h"
#include "driver/i2c.h"
#include "driver/spi_master.h"
#include "driver/uart.h"
#include "esp_log.h"
#include "esp_system.h"
#include "freertos/FreeRTOS.h"
#include "freertos/task.h"

#define LED_GPIO        2
#define GPIO1           3
#define GPIO2           4
#define GPIO3           5

#define UART_MODEM_TX   20
#define UART_MODEM_RX   21
#define UART_MODEM_NUM  UART_NUM_1

#define UART_CMD_NUM    UART_NUM_0

#define I2C_SCL         7
#define I2C_SDA         6
#define I2C_PORT        I2C_NUM_0

#define SPI_MOSI        9
#define SPI_MISO        10
#define SPI_CLK         11

#define SPI_CS_W5500    12
#define SPI_CS_SD       13
#define SPI_CS_S2LP     14

#define W5500_INT_GPIO  15
#define W5500_RST_GPIO  16

#define S2LP_SDN_GPIO   17

#define MODEM_PWR_GPIO  18

static const char *TAG = "BRINGUP";

static spi_device_handle_t spi_dev_w5500;
static spi_device_handle_t spi_dev_sd;
static spi_device_handle_t spi_dev_s2lp;

typedef enum {
    TEST_PASS = 0,
    TEST_FAIL = 1
} test_result_t;

typedef struct {
    const char *name;
    test_result_t (*fn)(void);
} test_case_t;

static void init_gpio(void)
{
    gpio_reset_pin(LED_GPIO);
    gpio_set_direction(LED_GPIO, GPIO_MODE_OUTPUT);

    gpio_reset_pin(GPIO1);
    gpio_set_direction(GPIO1, GPIO_MODE_OUTPUT);

    gpio_reset_pin(GPIO2);
    gpio_set_direction(GPIO2, GPIO_MODE_OUTPUT);

    gpio_reset_pin(GPIO3);
    gpio_set_direction(GPIO3, GPIO_MODE_OUTPUT);

    gpio_reset_pin(MODEM_PWR_GPIO);
    gpio_set_direction(MODEM_PWR_GPIO, GPIO_MODE_OUTPUT);
    gpio_set_level(MODEM_PWR_GPIO, 0);

    gpio_reset_pin(W5500_RST_GPIO);
    gpio_set_direction(W5500_RST_GPIO, GPIO_MODE_OUTPUT);
    gpio_set_level(W5500_RST_GPIO, 1);

    gpio_reset_pin(W5500_INT_GPIO);
    gpio_set_direction(W5500_INT_GPIO, GPIO_MODE_INPUT);

    gpio_reset_pin(S2LP_SDN_GPIO);
    gpio_set_direction(S2LP_SDN_GPIO, GPIO_MODE_OUTPUT);
    gpio_set_level(S2LP_SDN_GPIO, 1);

    ESP_LOGI(TAG, "GPIO initialized");
}

static void init_uart_modem(void)
{
    uart_config_t cfg = {
        .baud_rate = 115200,
        .data_bits = UART_DATA_8_BITS,
        .stop_bits = UART_STOP_BITS_1,
        .parity    = UART_PARITY_DISABLE,
        .flow_ctrl = UART_HW_FLOWCTRL_DISABLE,
        .source_clk = UART_SCLK_DEFAULT
    };

    uart_param_config(UART_MODEM_NUM, &cfg);
    uart_set_pin(UART_MODEM_NUM, UART_MODEM_TX, UART_MODEM_RX,
                 UART_PIN_NO_CHANGE, UART_PIN_NO_CHANGE);
    uart_driver_install(UART_MODEM_NUM, 4096, 0, 0, NULL, 0);

    ESP_LOGI(TAG, "Modem UART initialized");
}

static void init_uart_cmd(void)
{
    uart_config_t cfg = {
        .baud_rate = 115200,
        .data_bits = UART_DATA_8_BITS,
        .stop_bits = UART_STOP_BITS_1,
        .parity    = UART_PARITY_DISABLE,
        .flow_ctrl = UART_HW_FLOWCTRL_DISABLE,
        .source_clk = UART_SCLK_DEFAULT
    };

    uart_param_config(UART_CMD_NUM, &cfg);
    uart_set_pin(UART_CMD_NUM, UART_PIN_NO_CHANGE, UART_PIN_NO_CHANGE,
                 UART_PIN_NO_CHANGE, UART_PIN_NO_CHANGE);
    uart_driver_install(UART_CMD_NUM, 4096, 0, 0, NULL, 0);

    ESP_LOGI(TAG, "CMD UART initialized");
}

static void init_i2c(void)
{
    i2c_config_t cfg = {
        .mode = I2C_MODE_MASTER,
        .sda_io_num = I2C_SDA,
        .scl_io_num = I2C_SCL,
        .sda_pullup_en = GPIO_PULLUP_ENABLE,
        .scl_pullup_en = GPIO_PULLUP_ENABLE,
        .master.clk_speed = 100000
    };

    i2c_param_config(I2C_PORT, &cfg);
    i2c_driver_install(I2C_PORT, cfg.mode, 0, 0, 0);

    ESP_LOGI(TAG, "I2C initialized");
}

static void init_spi_bus(void)
{
    spi_bus_config_t buscfg = {
        .mosi_io_num = SPI_MOSI,
        .miso_io_num = SPI_MISO,
        .sclk_io_num = SPI_CLK,
        .quadwp_io_num = -1,
        .quadhd_io_num = -1,
        .max_transfer_sz = 4096
    };

    esp_err_t err = spi_bus_initialize(SPI2_HOST, &buscfg, SPI_DMA_CH_AUTO);
    if (err != ESP_OK) {
        ESP_LOGE(TAG, "SPI bus init failed: %d", err);
        return;
    }

    spi_device_interface_config_t devcfg_w5500 = {
        .clock_speed_hz = 10 * 1000 * 1000,
        .mode = 0,
        .spics_io_num = SPI_CS_W5500,
        .queue_size = 4
    };
    spi_bus_add_device(SPI2_HOST, &devcfg_w5500, &spi_dev_w5500);

    spi_device_interface_config_t devcfg_sd = {
        .clock_speed_hz = 8 * 1000 * 1000,
        .mode = 0,
        .spics_io_num = SPI_CS_SD,
        .queue_size = 4
    };
    spi_bus_add_device(SPI2_HOST, &devcfg_sd, &spi_dev_sd);

    spi_device_interface_config_t devcfg_s2lp = {
        .clock_speed_hz = 4 * 1000 * 1000,
        .mode = 0,
        .spics_io_num = SPI_CS_S2LP,
        .queue_size = 4
    };
    spi_bus_add_device(SPI2_HOST, &devcfg_s2lp, &spi_dev_s2lp);

    ESP_LOGI(TAG, "SPI bus and devices initialized");
}

static void modem_send_cmd(const char *cmd)
{
    uart_write_bytes(UART_MODEM_NUM, cmd, strlen(cmd));
}

static int modem_read_line(char *buf, int max_len, TickType_t timeout_ticks)
{
    int idx = 0;
    TickType_t start = xTaskGetTickCount();

    while (idx < max_len - 1) {
        uint8_t ch;
        int len = uart_read_bytes(UART_MODEM_NUM, &ch, 1, pdMS_TO_TICKS(10));
        if (len > 0) {
            if (ch == '\n') {
                break;
            }
            if (ch != '\r') {
                buf[idx++] = (char)ch;
            }
        }
        if ((xTaskGetTickCount() - start) > timeout_ticks) {
            break;
        }
    }
    buf[idx] = '\0';
    return idx;
}

static void modem_power_on(void)
{
    ESP_LOGI(TAG, "Powering on modem");
    gpio_set_level(MODEM_PWR_GPIO, 1);
    vTaskDelay(pdMS_TO_TICKS(1000));
    gpio_set_level(MODEM_PWR_GPIO, 0);
    vTaskDelay(pdMS_TO_TICKS(5000));
}

static esp_err_t w5500_hw_reset(void)
{
    gpio_set_level(W5500_RST_GPIO, 0);
    vTaskDelay(pdMS_TO_TICKS(10));
    gpio_set_level(W5500_RST_GPIO, 1);
    vTaskDelay(pdMS_TO_TICKS(100));

    ESP_LOGI(TAG, "W5500 hardware reset");
    return ESP_OK;
}

static esp_err_t w5500_spi_write_reg(uint16_t addr, uint8_t block, uint8_t value)
{
    uint8_t tx[4];
    uint8_t rx[4];

    tx[0] = (uint8_t)(addr >> 8);
    tx[1] = (uint8_t)(addr & 0xFF);
    tx[2] = block;
    tx[3] = value;

    spi_transaction_t t = {
        .length = 8 * sizeof(tx),
        .tx_buffer = tx,
        .rx_buffer = rx
    };

    return spi_device_transmit(spi_dev_w5500, &t);
}

static esp_err_t w5500_basic_init(void)
{
    ESP_ERROR_CHECK(w5500_hw_reset());
    ESP_LOGI(TAG, "W5500 basic init (skeleton)");
    return ESP_OK;
}

static esp_err_t sdcard_init_spi(void)
{
    ESP_LOGI(TAG, "SD card SPI init (skeleton)");
    return ESP_OK;
}

static void s2lp_hw_wakeup(void)
{
    gpio_set_level(S2LP_SDN_GPIO, 0);
    vTaskDelay(pdMS_TO_TICKS(10));
}

static esp_err_t s2lp_spi_write_reg(uint8_t addr, uint8_t value)
{
    uint8_t tx[2];
    uint8_t rx[2];

    tx[0] = addr;
    tx[1] = value;

    spi_transaction_t t = {
        .length = 8 * sizeof(tx),
        .tx_buffer = tx,
        .rx_buffer = rx
    };

    return spi_device_transmit(spi_dev_s2lp, &t);
}

static esp_err_t s2lp_basic_init(void)
{
    s2lp_hw_wakeup();
    ESP_LOGI(TAG, "S2LP basic init (skeleton)");
    return ESP_OK;
}

static test_result_t test_gpio_led(void)
{
    ESP_LOGI(TAG, "[TEST] GPIO_LED");
    gpio_set_level(LED_GPIO, 1);
    vTaskDelay(pdMS_TO_TICKS(50));
    gpio_set_level(LED_GPIO, 0);
    return TEST_PASS;
}

static test_result_t test_w5500_basic(void)
{
    ESP_LOGI(TAG, "[TEST] W5500_BASIC");
    if (w5500_basic_init() == ESP_OK) {
        return TEST_PASS;
    }
    return TEST_FAIL;
}

static test_result_t test_sdcard_basic(void)
{
    ESP_LOGI(TAG, "[TEST] SDCARD_BASIC");
    if (sdcard_init_spi() == ESP_OK) {
        return TEST_PASS;
    }
    return TEST_FAIL;
}

static test_result_t test_modem_at_basic(void)
{
    ESP_LOGI(TAG, "[TEST] MODEM_AT");
    char line[128];

    modem_power_on();
    modem_send_cmd("AT\r\n");

    TickType_t timeout = pdMS_TO_TICKS(8000);
    TickType_t start = xTaskGetTickCount();

    while ((xTaskGetTickCount() - start) < timeout) {
        int len = modem_read_line(line, sizeof(line), pdMS_TO_TICKS(1000));
        if (len > 0) {
            ESP_LOGI(TAG, "Modem: %s", line);
            if (strstr(line, "OK") != NULL) {
                ESP_LOGI(TAG, "[TEST] MODEM_AT PASS");
                return TEST_PASS;
            }
        }
    }

    ESP_LOGE(TAG, "[TEST] MODEM_AT FAIL (no OK)");
    return TEST_FAIL;
}

static test_result_t test_s2lp_basic(void)
{
    ESP_LOGI(TAG, "[TEST] S2LP_BASIC");
    if (s2lp_basic_init() == ESP_OK) {
        return TEST_PASS;
    }
    return TEST_FAIL;
}

static const test_case_t g_tests[] = {
    { "GPIO_LED",   test_gpio_led },
    { "W5500_BASIC", test_w5500_basic },
    { "SDCARD_BASIC", test_sdcard_basic },
    { "MODEM_AT",   test_modem_at_basic },
    { "S2LP_BASIC", test_s2lp_basic }
};

static const size_t g_test_count = sizeof(g_tests) / sizeof(g_tests[0]);

static void send_result_line(const char *name, test_result_t res)
{
    printf("{\"type\":\"result\",\"name\":\"%s\",\"result\":\"%s\"}\n",
           name,
           (res == TEST_PASS) ? "PASS" : "FAIL");
}

static void handle_command(const char *cmd)
{
    if (strcmp(cmd, "LIST") == 0) {
        for (size_t i = 0; i < g_test_count; i++) {
            printf("{\"type\":\"test\",\"name\":\"%s\"}\n", g_tests[i].name);
        }
        return;
    }

    if (strncmp(cmd, "RUN ", 4) == 0) {
        const char *name = cmd + 4;

        if (strcmp(name, "ALL") == 0) {
            for (size_t i = 0; i < g_test_count; i++) {
                test_result_t r = g_tests[i].fn();
                send_result_line(g_tests[i].name, r);
            }
            return;
        }

        for (size_t i = 0; i < g_test_count; i++) {
            if (strcmp(name, g_tests[i].name) == 0) {
                test_result_t r = g_tests[i].fn();
                send_result_line(g_tests[i].name, r);
                return;
            }
        }

        printf("{\"type\":\"error\",\"msg\":\"UNKNOWN_TEST\"}\n");
        return;
    }

    printf("{\"type\":\"error\",\"msg\":\"UNKNOWN_CMD\"}\n");
}

static void command_task(void *arg)
{
    char buf[128];
    int idx = 0;

    while (1) {
        uint8_t ch;
        int len = uart_read_bytes(UART_CMD_NUM, &ch, 1, pdMS_TO_TICKS(50));
        if (len > 0) {
            if (ch == '\n' || ch == '\r') {
                buf[idx] = '\0';
                if (idx > 0) {
                    handle_command(buf);
                }
                idx = 0;
            } else if (idx < (int)sizeof(buf) - 1) {
                buf[idx++] = (char)ch;
            }
        }
    }
}

static void blink_task(void *param)
{
    while (1) {
        gpio_set_level(LED_GPIO, 1);
        vTaskDelay(pdMS_TO_TICKS(500));
        gpio_set_level(LED_GPIO, 0);
        vTaskDelay(pdMS_TO_TICKS(500));
    }
}

void app_main(void)
{
    ESP_LOGI(TAG, "Bring-up firmware starting");

    init_gpio();
    init_uart_modem();
    init_uart_cmd();
    init_i2c();
    init_spi_bus();

    xTaskCreate(blink_task, "blink", 2048, NULL, 1, NULL);
    xTaskCreate(command_task, "cmd", 4096, NULL, 4, NULL);

    ESP_LOGI(TAG, "Ready. Commands: LIST, RUN <name>, RUN ALL");
}
```

### How to use this from your PC

1. Connect to the board’s **UART0** (same as default console) at 115200.
2. Type commands followed by newline:

- `LIST` → board prints available tests as JSON lines
- `RUN ALL` → runs all tests, prints JSON result lines
- `RUN MODEM_AT` → runs just the modem test

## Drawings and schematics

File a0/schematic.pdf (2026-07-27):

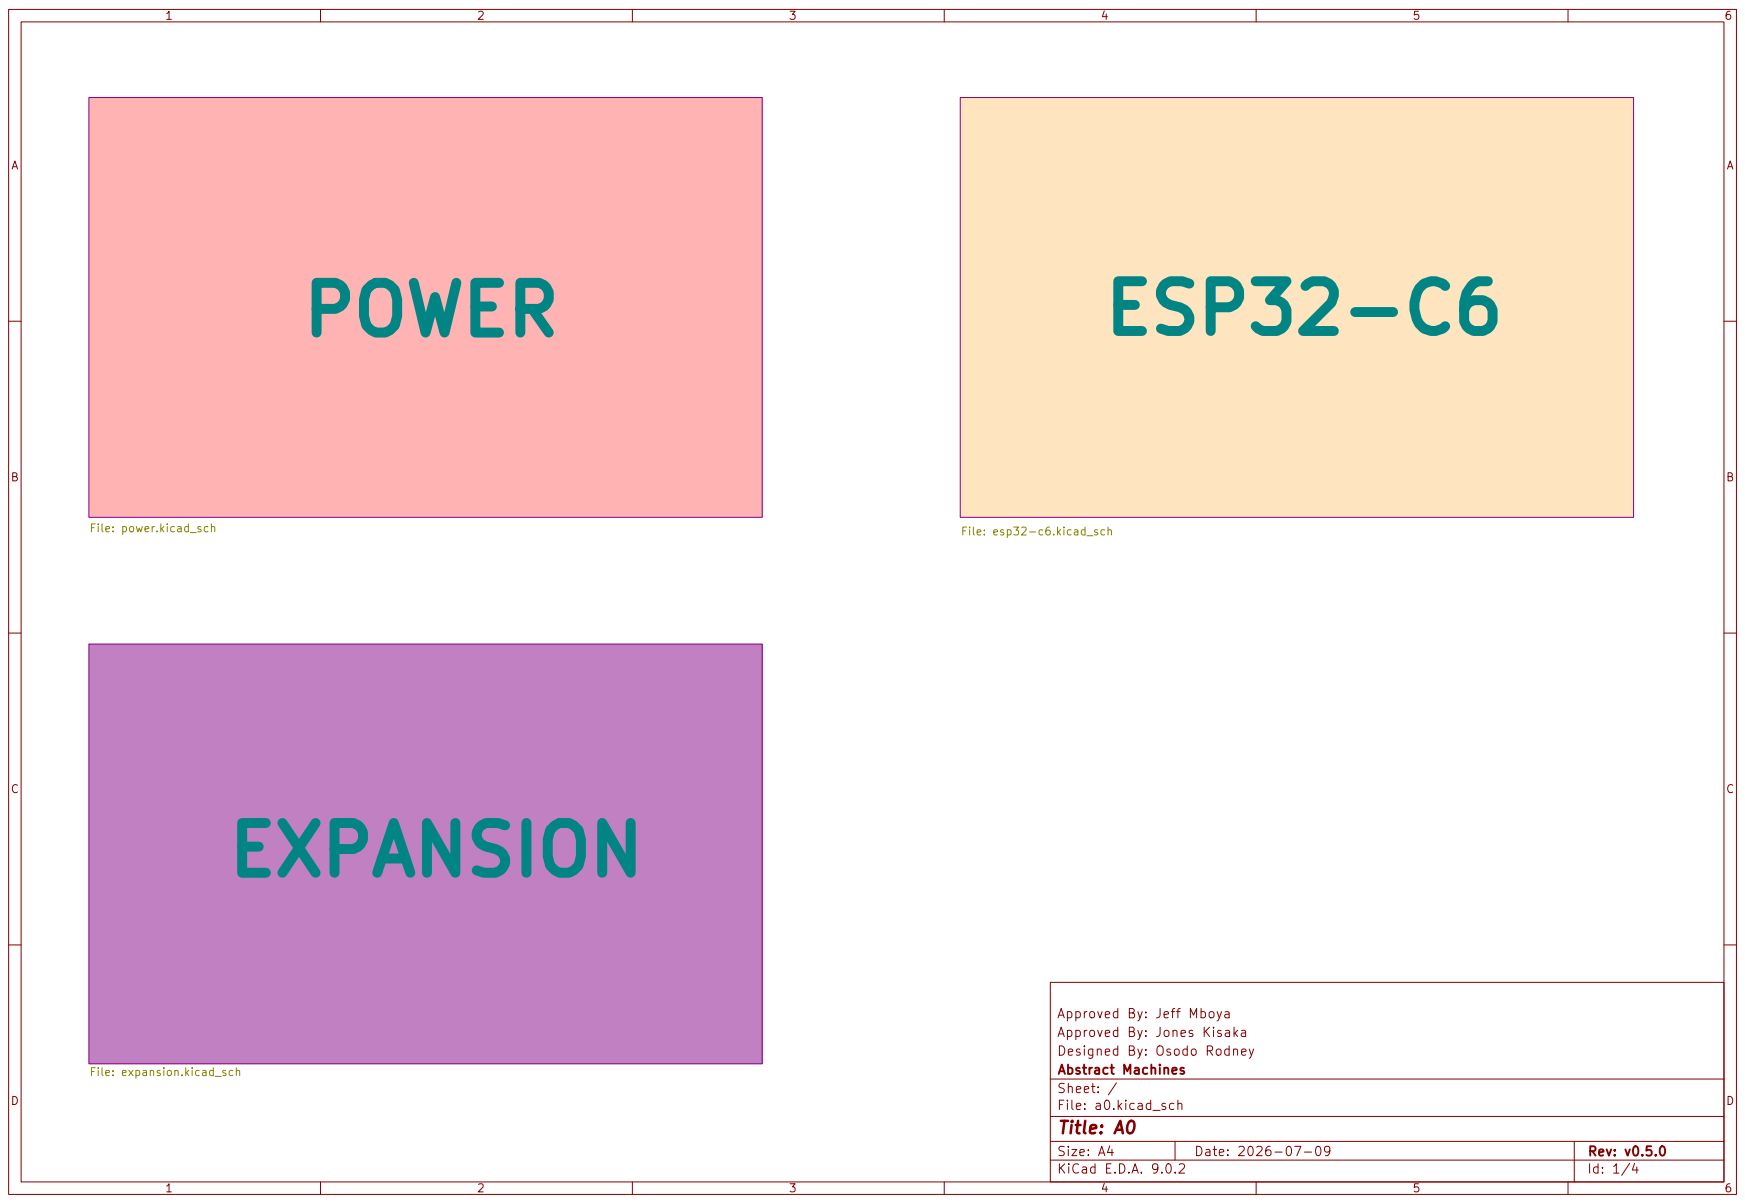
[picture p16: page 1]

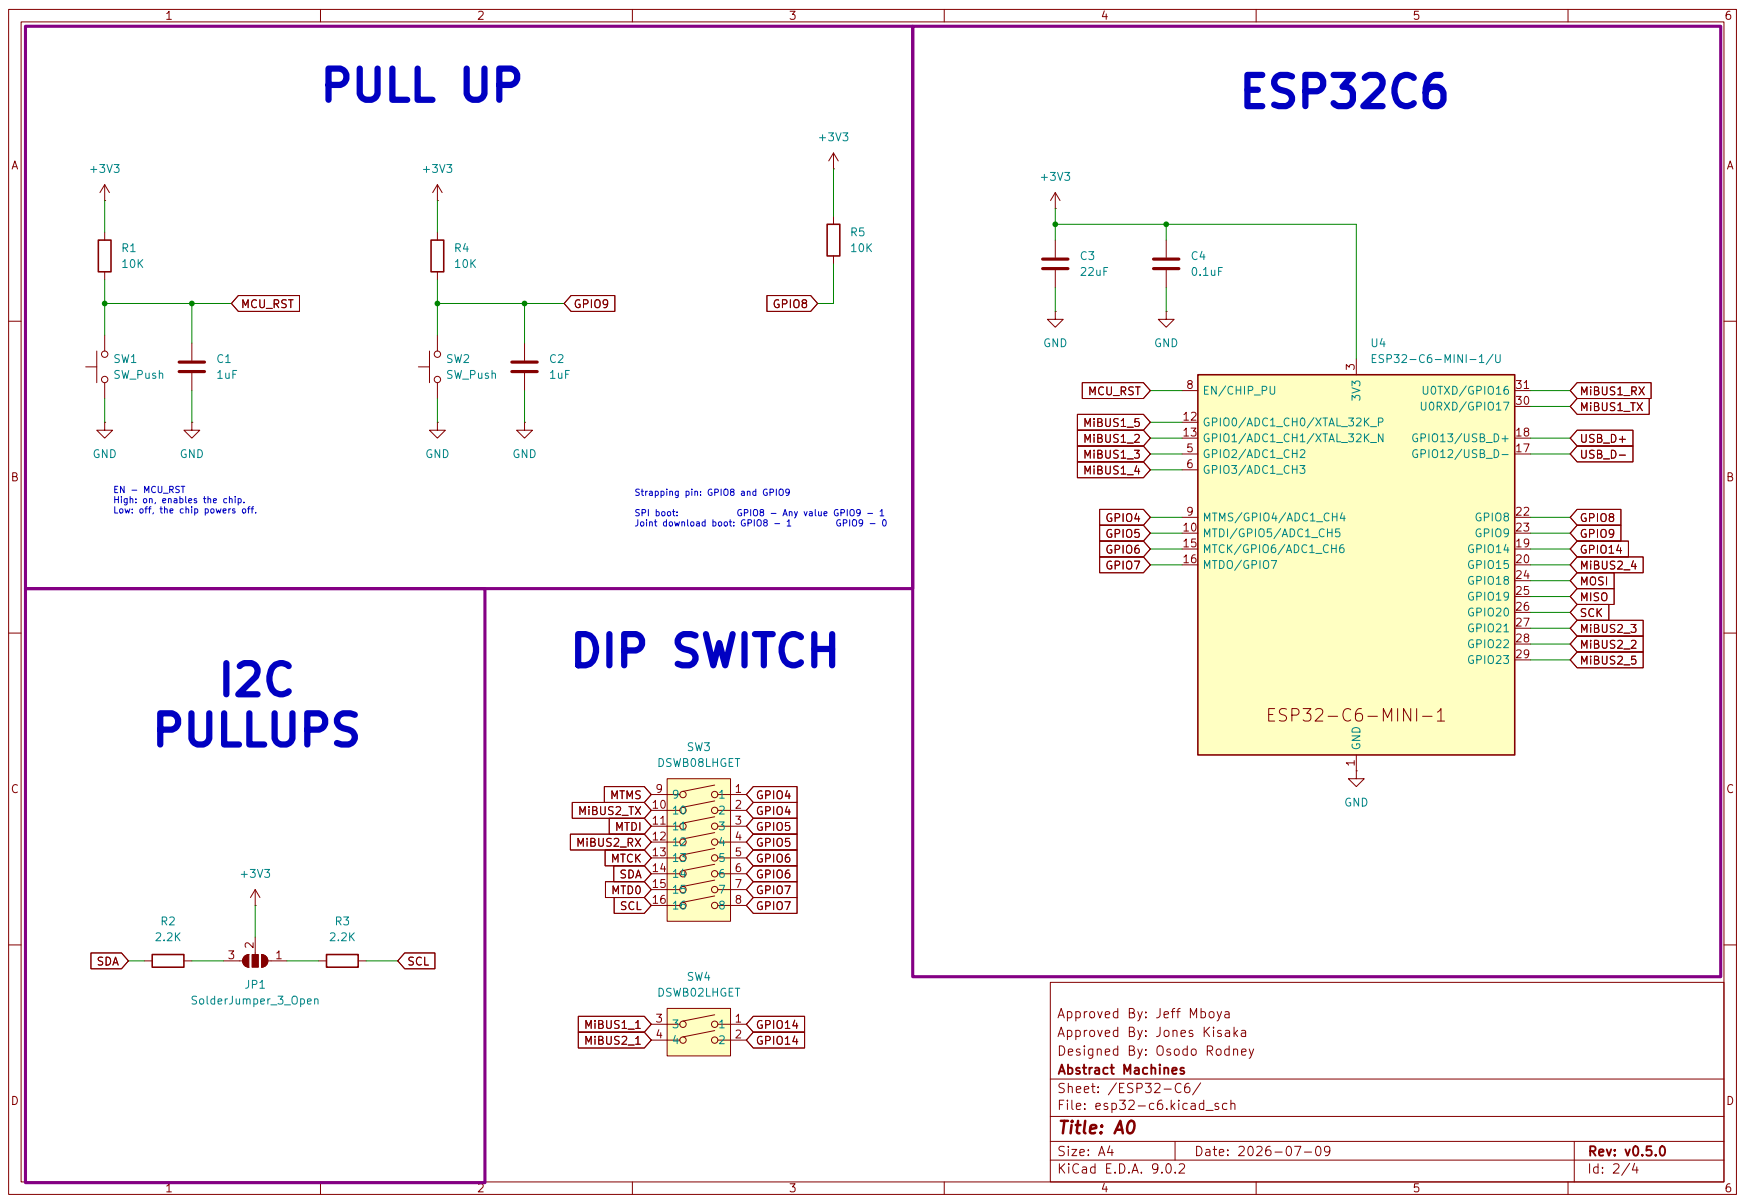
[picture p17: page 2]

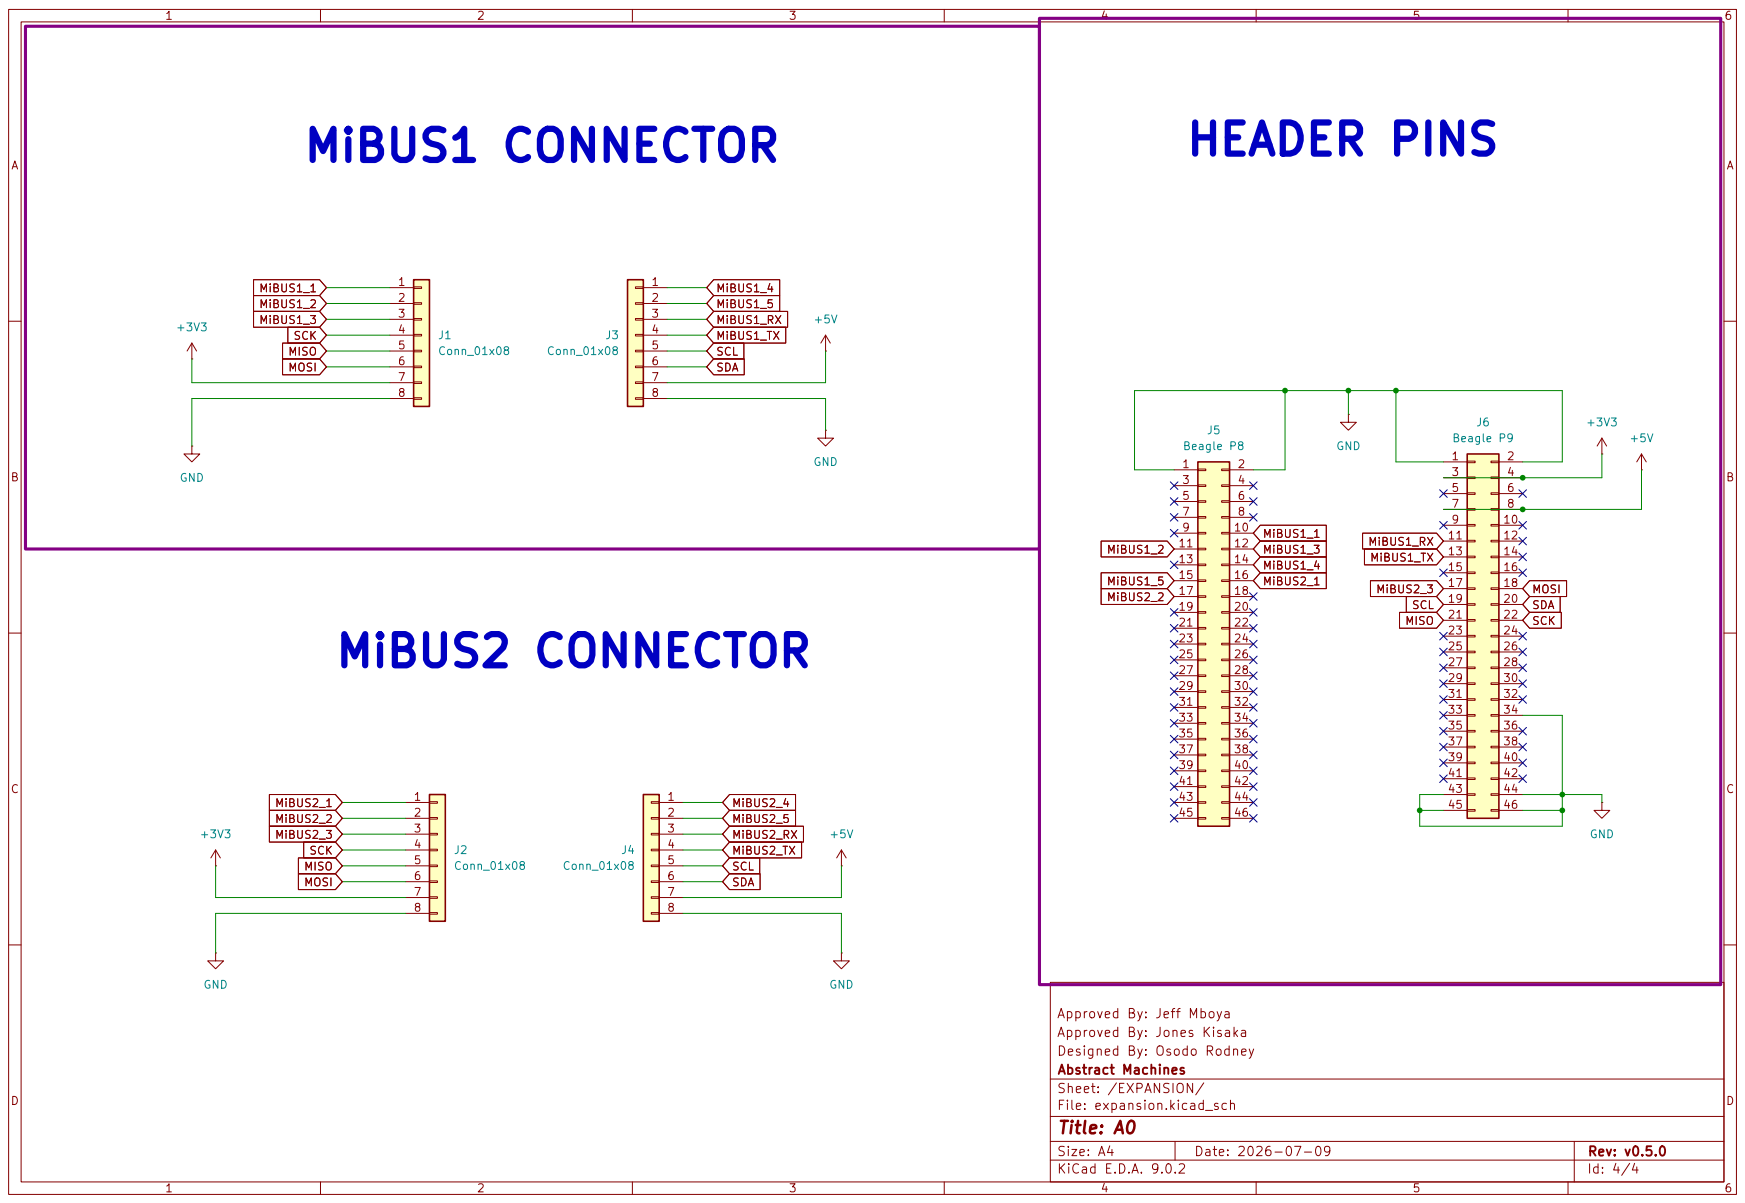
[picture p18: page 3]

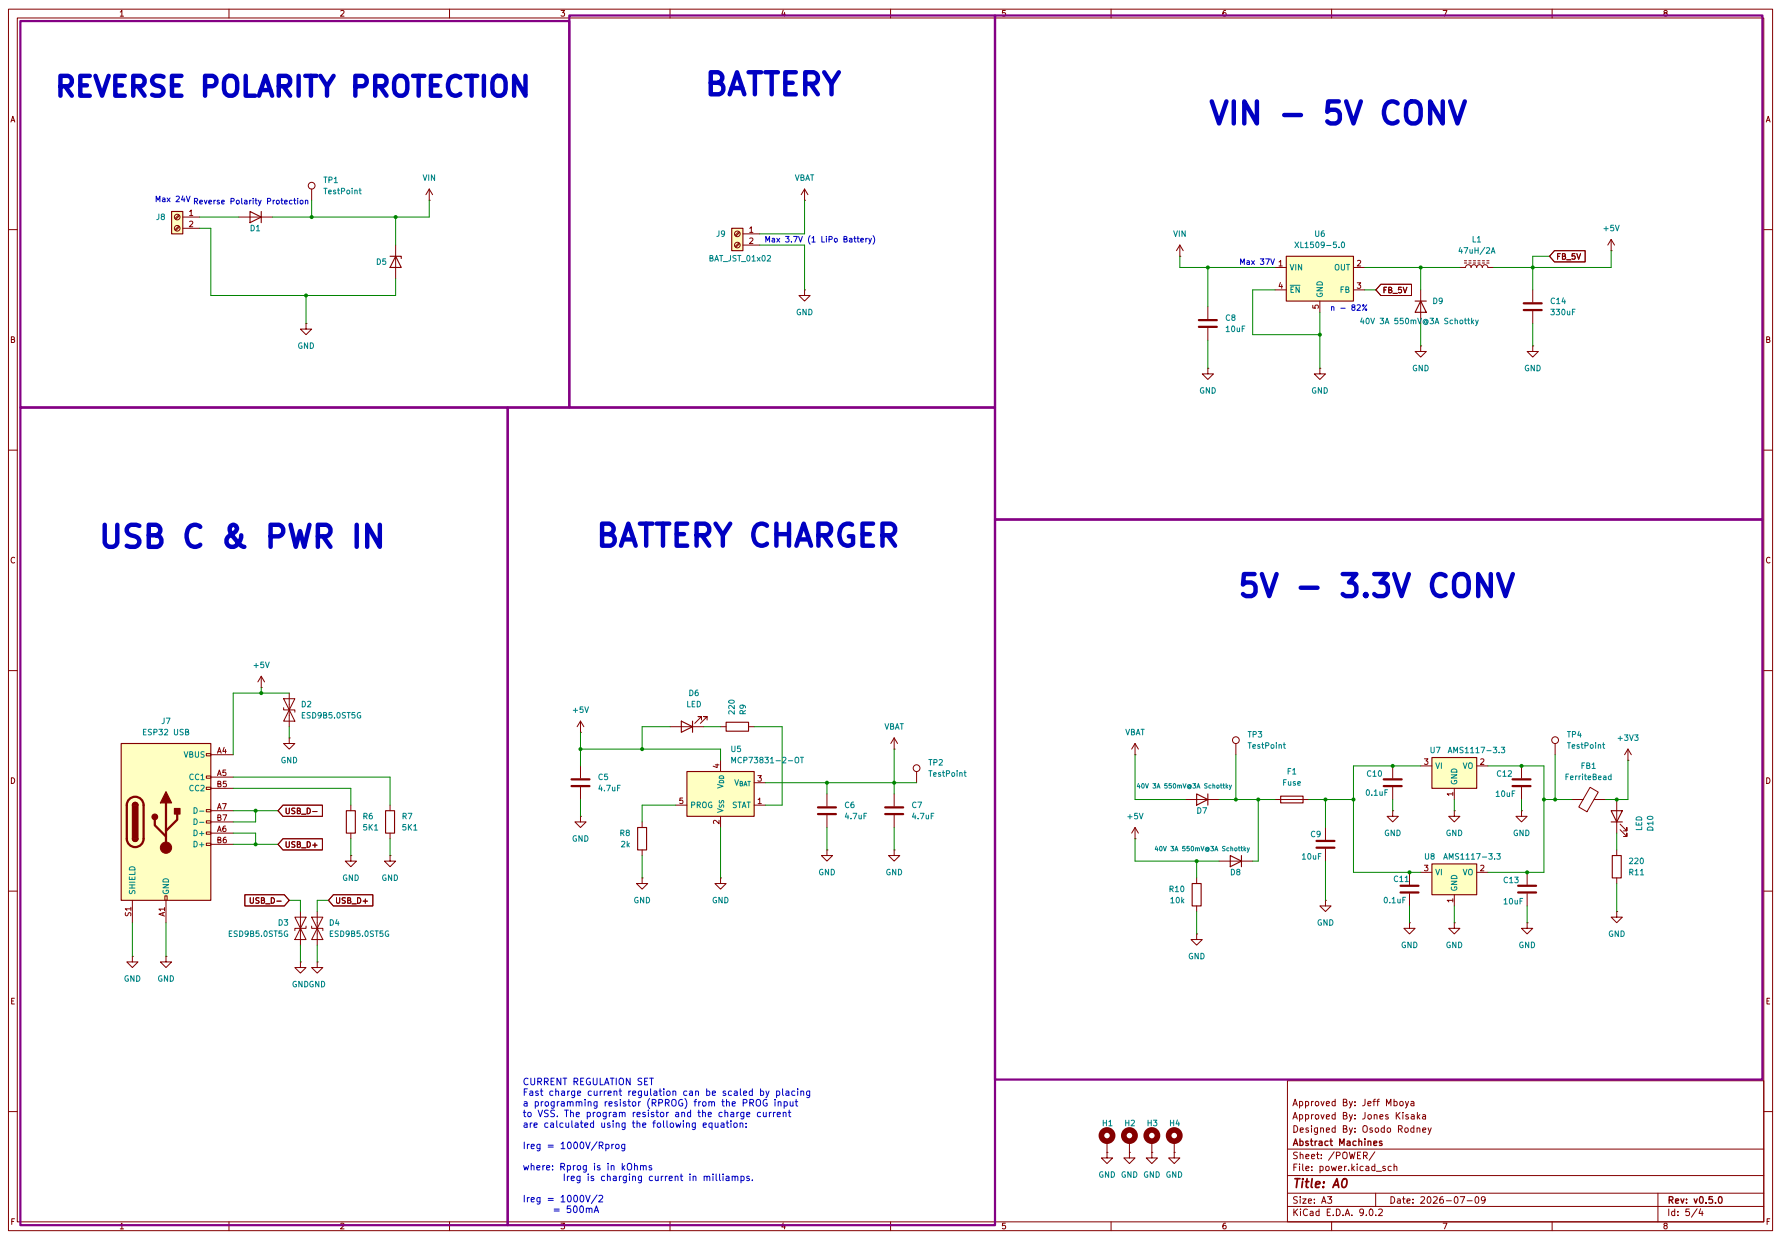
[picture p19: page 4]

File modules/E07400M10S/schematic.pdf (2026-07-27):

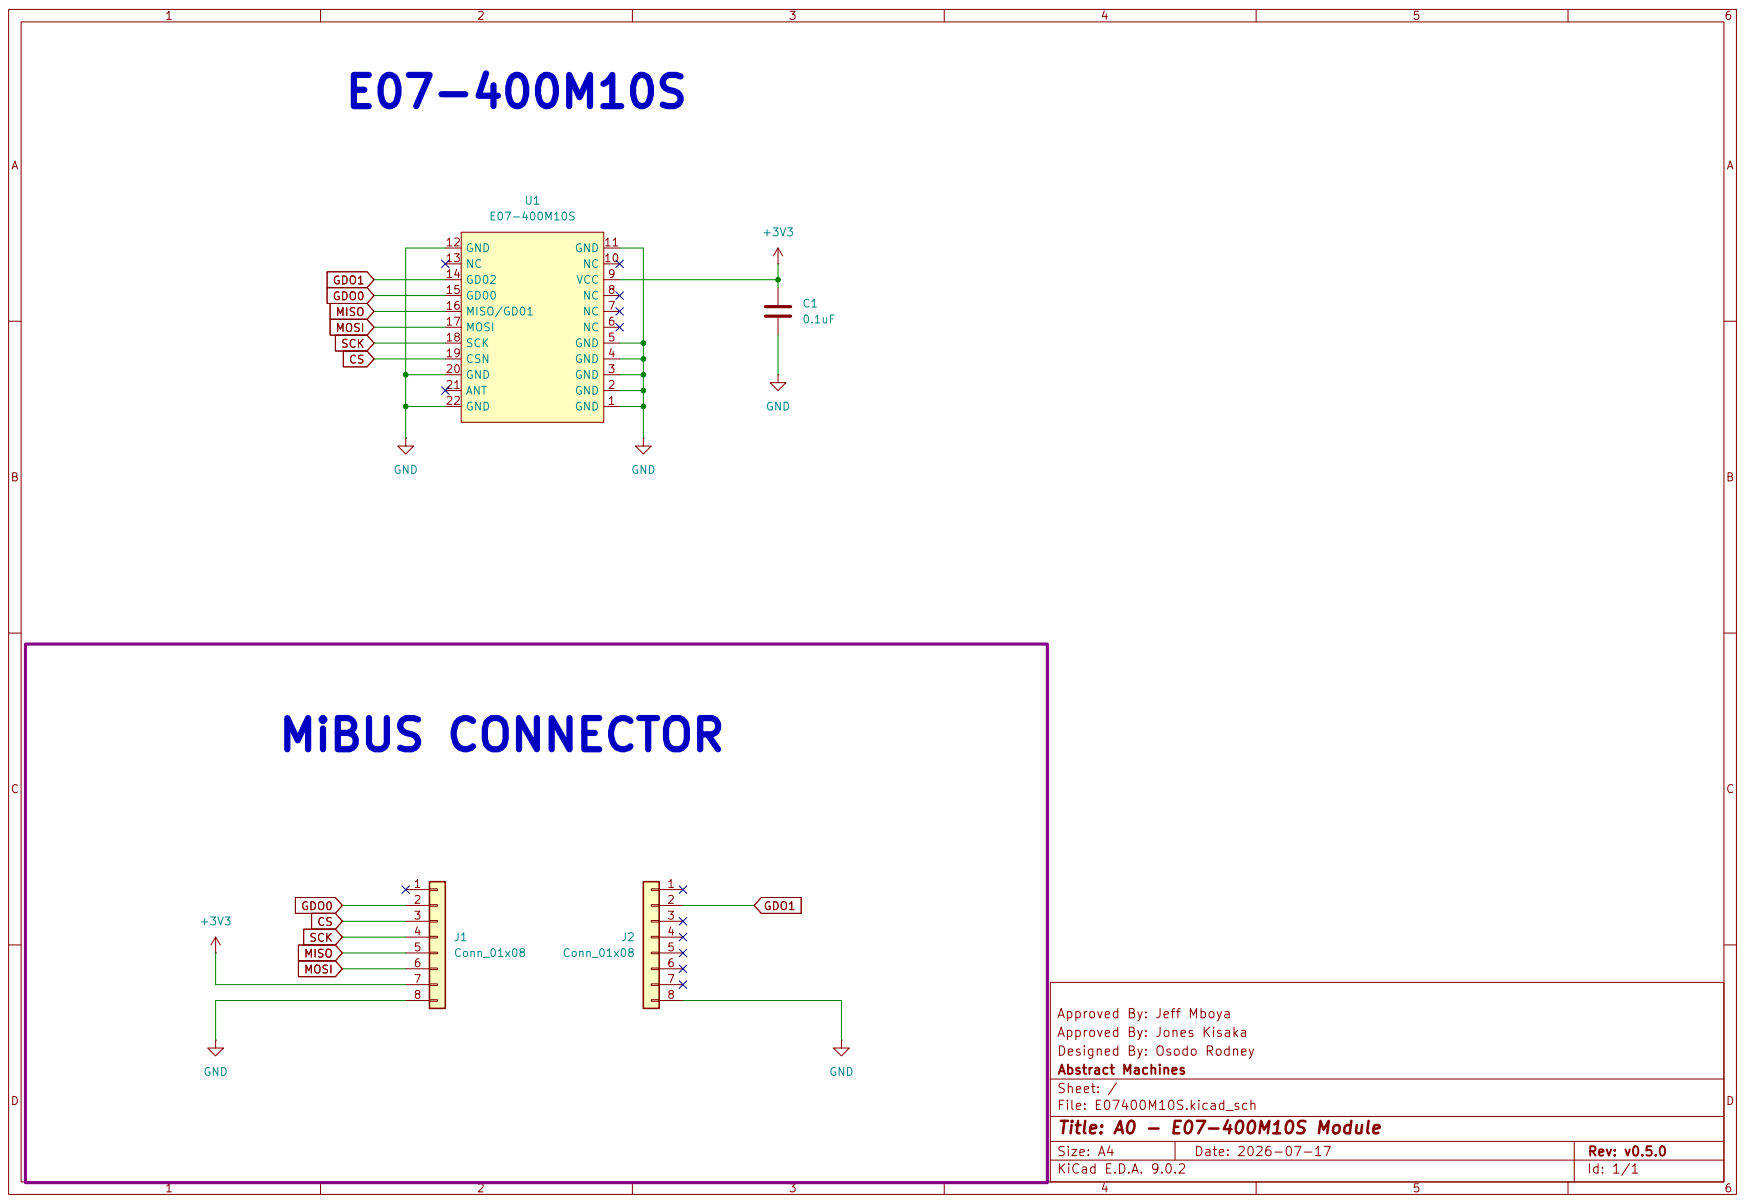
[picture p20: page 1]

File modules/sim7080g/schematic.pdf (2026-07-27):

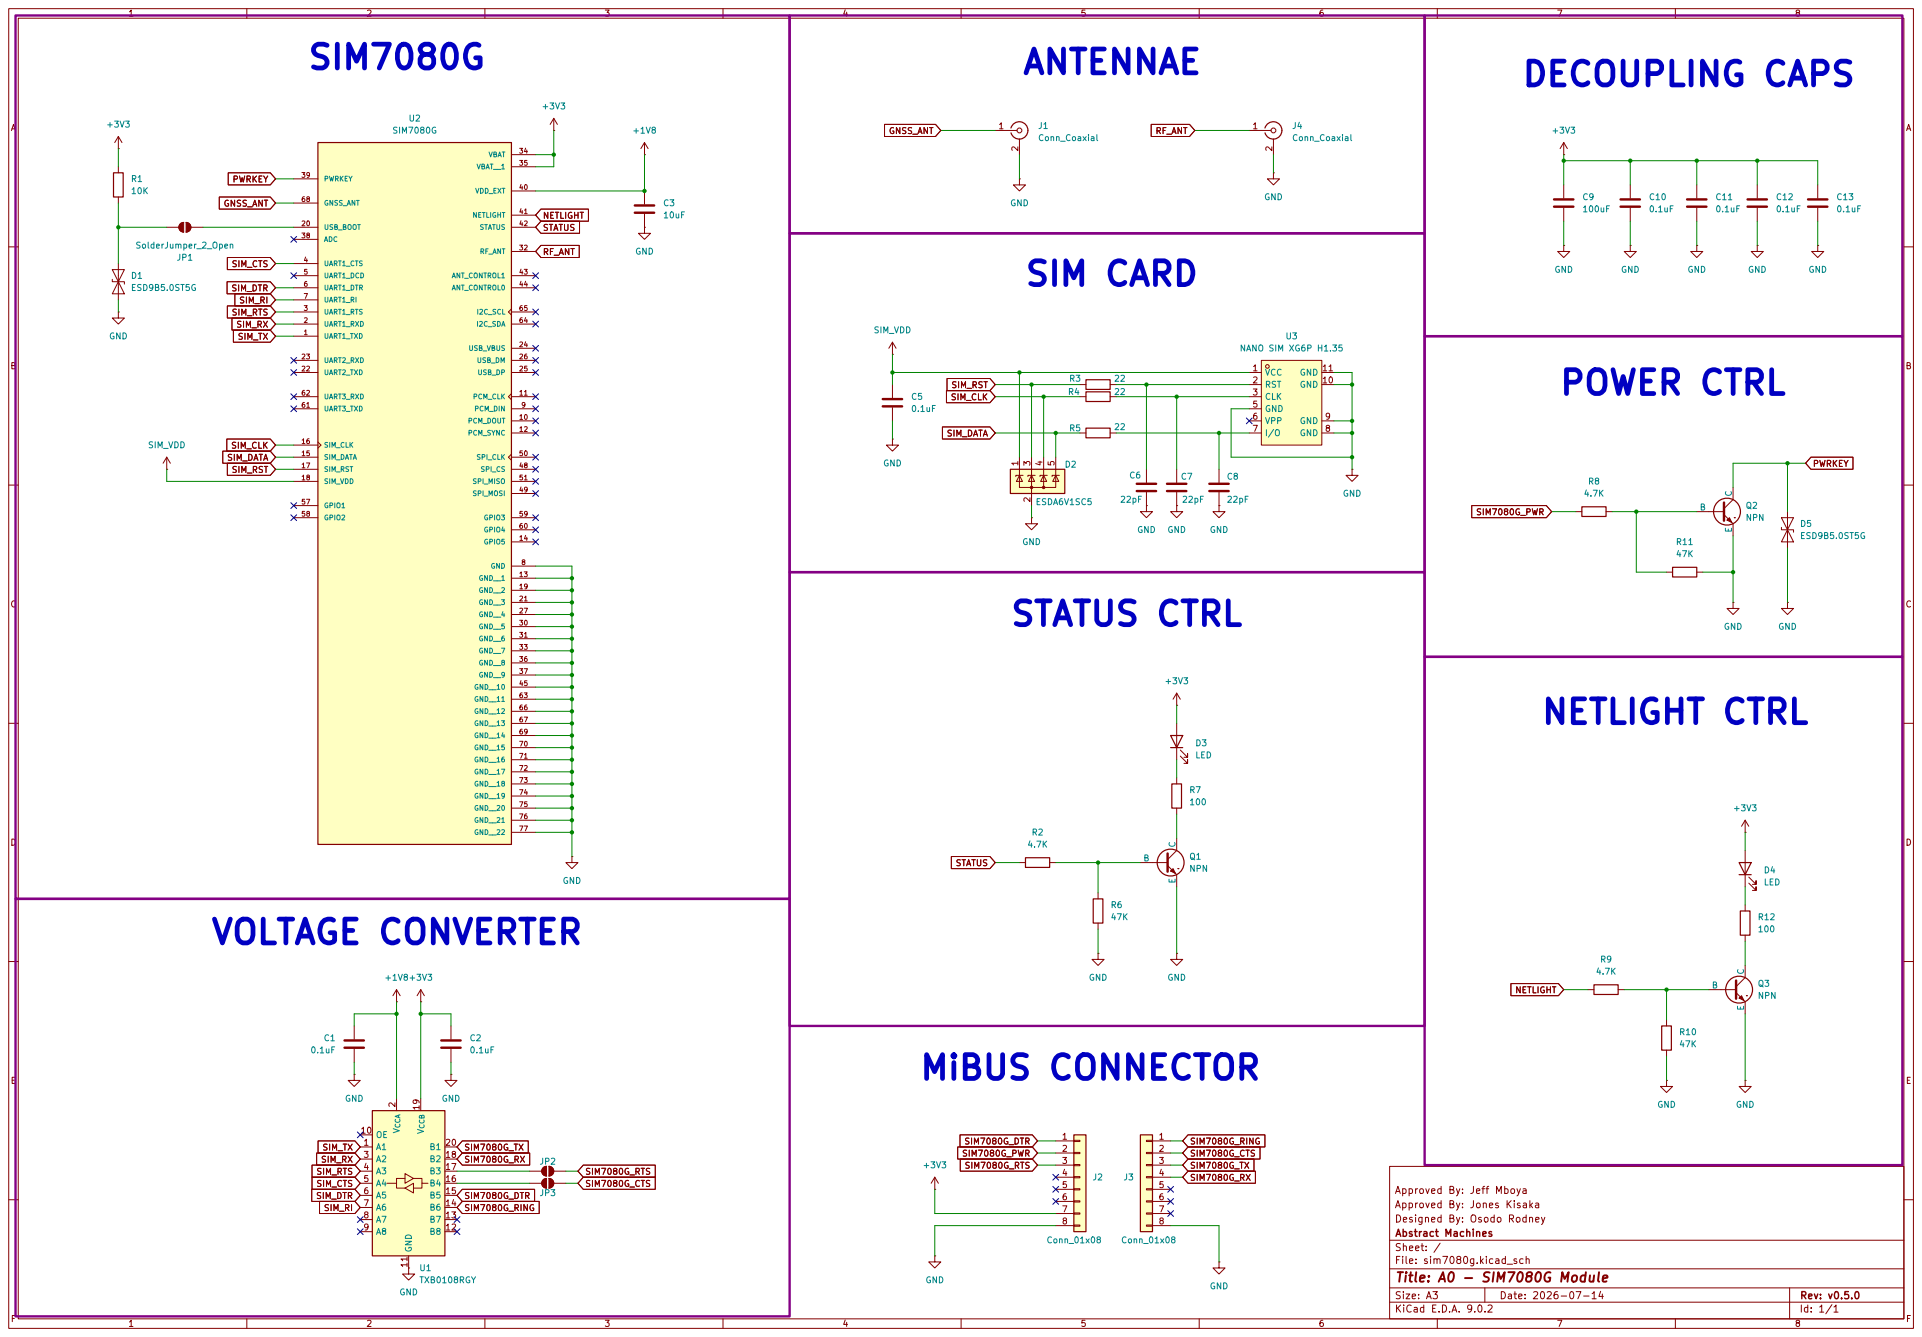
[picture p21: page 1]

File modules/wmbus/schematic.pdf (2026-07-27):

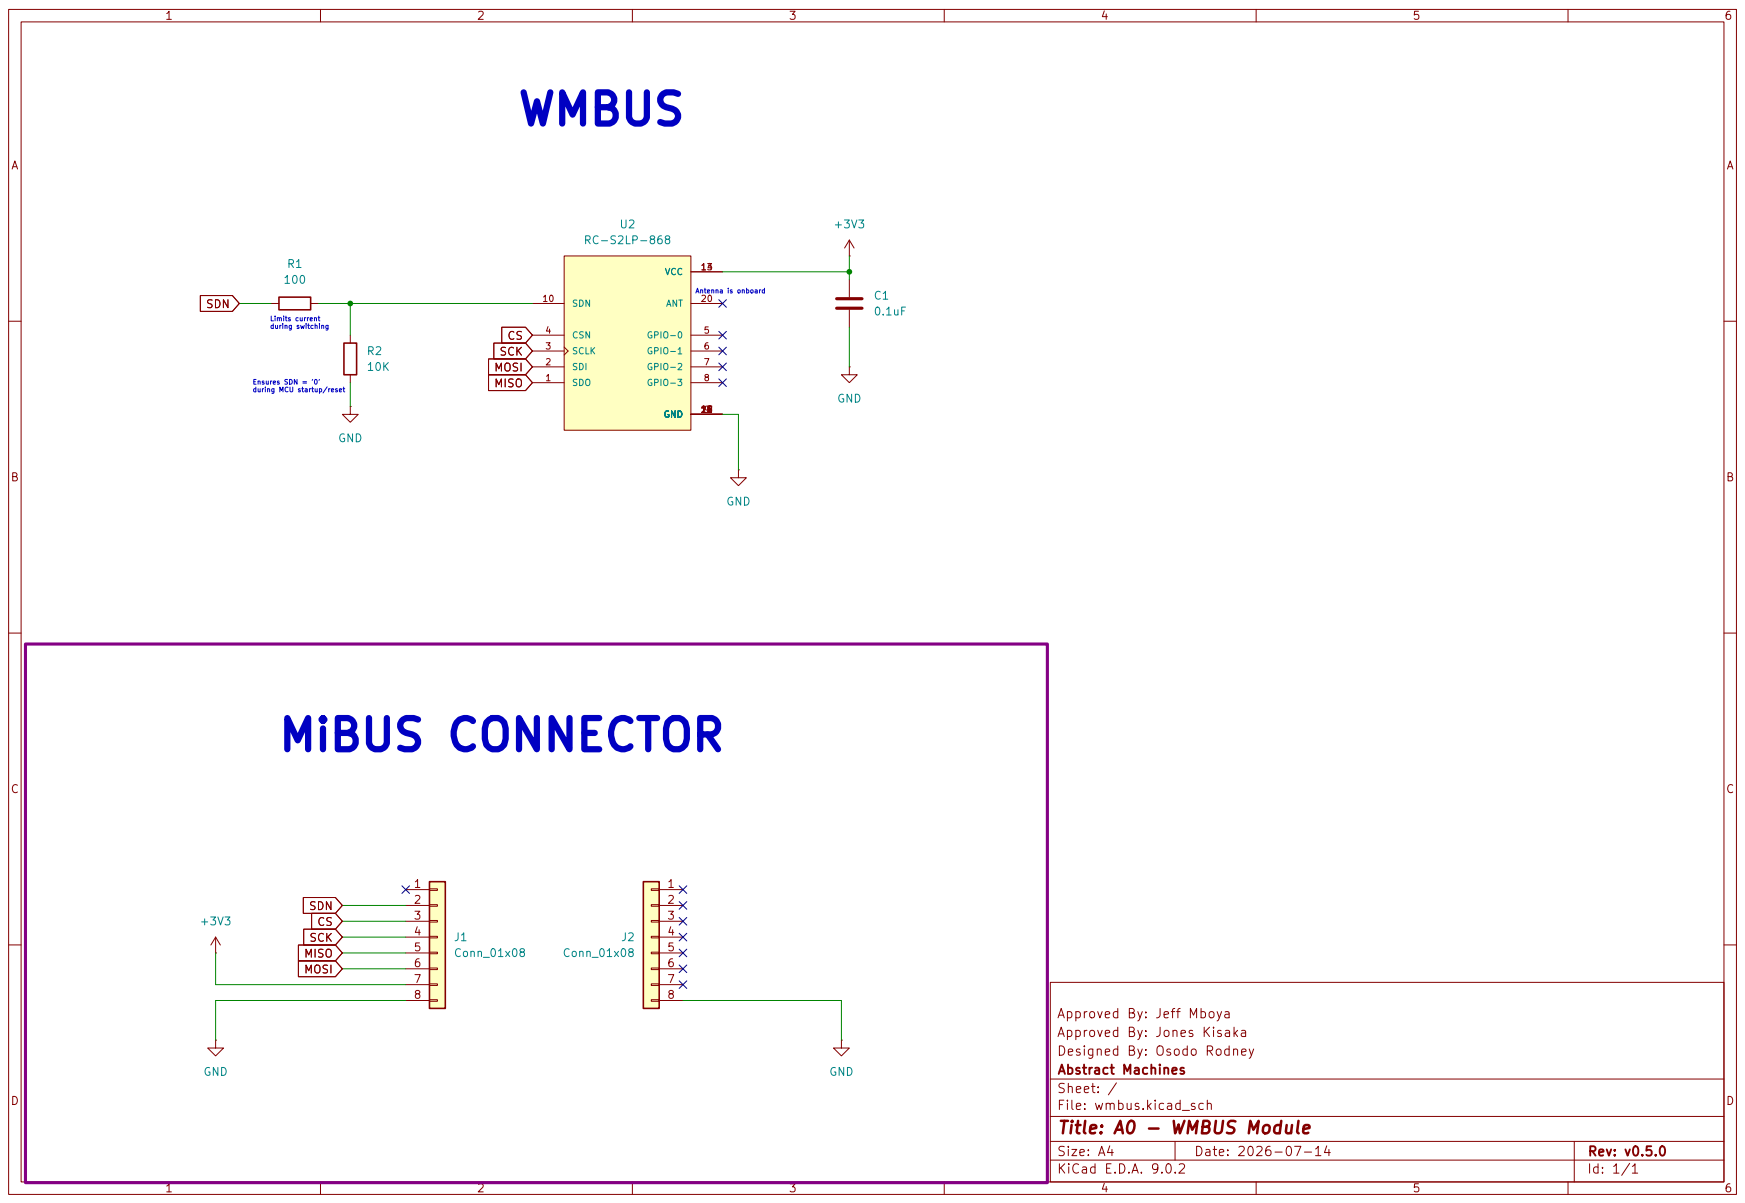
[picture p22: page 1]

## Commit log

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2024-11-21 Add coin battery holder
    [BMS.kicad_sch]
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2024-11-22 Convert from 2 to 4 layers
    [e-key-slot.kicad_pcb]
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2024-11-22 Replace dual holder with single holder
    [e-key-slot.kicad_pcb, e-key-slot.kicad_sch, e-key-socket.kicad_sch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]
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2024-11-22 Fix power symbols; remove LED
    [e-key-slot.kicad_pcb, e-key-socket.kicad_sch]
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2024-11-25 Add screw hole and addmore ground connection
    [e-key-slot.kicad_pcb, e-key-slot.kicad_sch, e-key-socket.kicad_sch]
2024-11-25 Add ground plane; increase +9v track width
    [e-key-slot.kicad_pcb]
2024-11-26 fix: fill copper layer
    [e-key-slot.kicad_pcb]
2024-11-26 feat: update PCB image
    [e-key-slot.kicad_pcb]
2024-11-26 fix: text formatting and modify gitignore
    [e-key-slot.kicad_sch, e-key-socket.kicad_sch]
2024-11-26 feat: initial design with sim7080G module
    [am-iot-gateway.kicad_pcb, am-iot-gateway.kicad_sch, connector.kicad_sch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]
2024-11-26 feat: minimal module with compute alone
    [am-iot-gateway.kicad_pcb, am-iot-gateway.kicad_sch, bom.csv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]
2024-11-26 refactor: change to JLCPCB as production and assembly
    [am-iot-gateway.kicad_pcb, bom.csv, connector.kicad_sch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]
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2024-11-27 Fix right angled tracks
    [am-iot-gateway.kicad_pcb, output.kicad_pcb]
2024-11-27 Update level shifter schematic
    [am-iot-gateway.kicad_sch, connector.kicad_sch, peripherals.kicad_sch]
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2024-11-27 Place components on PCB
    [am-iot-gateway.kicad_pcb]
2024-11-27 Add power and ground planes
    [am-iot-gateway.kicad_pcb]
2024-11-27 Add ground and power planes
    [am-iot-gateway.kicad_pcb]
2024-11-27 Fix floating track
    [am-iot-gateway.kicad_pcb]
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2024-11-27 feat: add wmbus module
    [wmbus.kicad_pcb, wmbus.kicad_sch]
2024-11-27 fix: routing mbus
    [wmbus.kicad_pcb, wmbus.kicad_sch]
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2024-11-27 fix: remodify board to be a baseboard
    [am-iot-gateway.kicad_pcb, connector.kicad_sch, peripherals.kicad_sch]
2024-12-02 feat: combine wmbus and sim7080
    [am-iot-gateway.kicad_pcb, am-iot-gateway.kicad_sch, connector.kicad_sch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]
2024-12-02 fix: cleanup remove global production dir
    [bom.csv, designators.csv, positions.csv]
2025-02-27 feat(s0-base-board): add s0 base board schematic
    [connector.kicad_sch, ethernet.kicad_sch, power.kicad_sch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]
2025-02-27 feat(pcb): update schematic with PCB
    [connector.kicad_sch, ethernet.kicad_sch, power.kicad_sch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]
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2025-03-06 feat: add production files
    [bom.csv, designators.csv, positions.csv]
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2025-03-07 feat(s0): add top board PCB and schematic
    [COMM-SMD_30P-L25.4-W12.7-P1.27_RC1180-MBUS3.step, SIM-SMD_NANO-SIM-XG6P-H1.35.step, SIM7080G.step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]
2025-03-10 Complete Schematic and PCB
    [s0.kicad_pcb]
2025-03-12 Documentation added onto Schematic
    [connector.kicad_sch, ethernet.kicad_sch, power.kicad_sch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]
2025-03-13 feat(base): add schematic notes and PCB notes
    [bom.csv, connector.kicad_sch, designators.csv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]
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2025-03-13 chore: add production files
    [bom.csv, connector.kicad_sch, designators.csv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]
2025-03-17 chore:Modify BOM in production
    [connector.kicad_sch, lora.kicad_sch, mcu.kicad_sch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]
2025-03-18 chore: Updated BOM and PCB
    [connector.kicad_sch, ethernet.kicad_sch, power.kicad_sch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]
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2025-03-19 chore: Modified Pin Header Direction1
    [s0.kicad_pcb]
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2025-03-21 Modified Schematics and BOM
    [bom.csv, connector.kicad_sch, designators.csv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]
2025-03-21 chore: route the board with changes
    [RAK3172.step, connector.kicad_sch, lora.kicad_sch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]
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2025-03-24 fix(routing): beagle V fire connections
    [connector.kicad_sch, s0.kicad_pcb]
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2025-03-24 Updated PCB from review
    [bom.csv, connector.kicad_sch, designators.csv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]
2025-03-24 Updated PCB from reviews
    [bom.csv, connector.kicad_sch, designators.csv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]
2025-03-25 Conflict Resolve
    [s0.kicad_pcb]
2025-03-26 chore(production): Add BOM and gerber files
    [connector.kicad_sch, designators.csv, lora.kicad_sch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]
2025-03-26 chore(production): Generate BOM and gerber files
    [connector.kicad_sch, designators.csv, ethernet.kicad_sch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]
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2025-04-02 fix: add fuse, ferrite bead and fixes from gpt
    [connector.kicad_sch, lora.kicad_sch, mcu.kicad_sch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]
2025-04-02 fix: add logo name of the board on silkscreen
    [s0.kicad_pcb]
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2025-04-07 fix(silkscreen): Add logo and website name
    [s0-base-board.kicad_pcb, s0.kicad_pcb]
2025-04-08 style: add new aligned logo
    [s0-base-board.kicad_pcb, s0.kicad_pcb]
2025-04-08 chore: finalize production files for s0
    [bom.csv, connector.kicad_sch, designators.csv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]
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2025-04-08 fix: populate correct bom
    [bom.csv, connector.kicad_sch, designators.csv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]
2025-05-05 feat(s0): add GPIO mux for wired mbus and sd card
    [connector.kicad_sch, lora.kicad_sch, mcu.kicad_sch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]
2025-05-06 fix: route PCB
    [bom.csv, connector.kicad_sch, designators.csv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]
2025-05-06 feat: add sd card and wired mbus support
    [connector.kicad_sch, ethernet.kicad_sch, mbus.kicad_sch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]
2025-05-06 feat(base-board): route and add wirembus support
    [bom.csv, connector.kicad_sch, designators.csv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]
2025-05-08 fix: add 3d models for pin connector and sd card
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2025-05-09 feat: add open solder jumper to switch off wired mbus
    [connector.kicad_sch, designators.csv]
2025-05-12 fix: add male jumper connections for UART
    [bom.csv, connector.kicad_sch, designators.csv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]
2025-05-14 fix: add UART switch for NBIoT and external connector for RS232 connector
    [bom.csv, connector.kicad_sch, designators.csv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]
2025-05-21 feat(s0): migrate from c3 to c6
    [bom.csv, connector.kicad_sch, designators.csv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]
2025-05-22 feat(production): export gerber and bom for s0 and baseboard
    [bom.csv, designators.csv, positions.csv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]
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2025-05-22 fix(s0): add UART header
    [bom.csv, connector.kicad_sch, designators.csv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]
2025-05-23 fix: silkscreen
    [designators.csv]
2025-05-23 fix: elongate s0-usb side
    [connector.kicad_sch, designators.csv, positions.csv]
2025-05-26 fix(s0): add jtag on silkscreen
2025-06-12 fix(production): make changes needed by JLCPCB for production run
    [bom.csv, designators.csv, ethernet.kicad_sch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]
2025-07-05 SD Card Pin change
    [connector.kicad_sch, ethernet.kicad_sch, mbus.kicad_sch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]
2025-07-07 Ethernet UART substrate resistors addition
    [ethernet.kicad_sch, power.kicad_sch]
2025-07-08 wip: rework s0
    [connector.kicad_sch, lora.kicad_sch, mcu.kicad_sch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]
2025-07-08 4 layered update and impedance matching
    [connector.kicad_sch, ethernet.kicad_sch, mbus.kicad_sch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]
2025-07-09 Pin Changes. Baseboard-S0 sync
    [bom.csv, connector.kicad_sch, designators.csv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]
2025-07-09 fix(s0): update schematic and PCBs
    [connector.kicad_sch, mcu.kicad_sch, power.kicad_sch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]
2025-07-09 RJ45 3D model addition.
    [CRJ011-ML1-TH--3DModel-STEP-1.STEP]
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2025-07-14 fix(s0): reroute
    [connector.kicad_sch]
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2025-07-29 fix: change 100nF C0402 to be the same
    [bom.csv, designators.csv, positions.csv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]
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2025-07-29 fix: add ground plane on top
2025-08-21 fix: rename the board from M0 to S0 (#15)
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2025-11-14 Fixed power routing v2
    [s0.kicad_pcb]
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2025-12-03 DRC fixes for Baseboard Routing
    [ethernet.kicad_sch, s0-base-board.kicad_pcb, sdcard.kicad_sch]
2025-12-09 Revert "Fixed power routing v2"
    This reverts commit 8e9cf23c81f4df8c308f22e854d99db006ce0926.
    [s0.kicad_pcb]
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2025-12-09 NOISSUE - Update s0 to v3 with corrections from v2 (#20)
    * schematic update for revision 3
    * feat: finish routing on S0
    * DRC corrections and review changes
    ---------
    [COMM-SMD_30P-L25.4-W12.7-P1.27_RC1180-MBUS3.step, RAK3172--3DModel-STEP-100311.STEP, RAK3172.step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]
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2026-07-03 Rename s0 to a0 and remain with 2 modules
    [Blue_Screw_Terminal_3DModel-STEP-1.STEP, COMM-SMD_30P-L25.4-W12.7-P1.27_RC1180-MBUS3.step, CRJ011-ML1-TH--3DModel-STEP-1.STEP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]
2026-07-03 KICAD fix after manual renaming
    [a0-base-board.kicad_pcb, a0.kicad_pcb]
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2026-07-14 fix(A0): update to use modules
    [BOM-wmbus.csv, C8404.step, C99413.step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]
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2026-07-22 cross check wmbus module is ready for fabrication
    [wmbus-CuBottom.gbr, wmbus-CuTop.gbr, wmbus-EdgeCuts.gbr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]
2026-07-22 cross check sim7080G module is ready for fabrication
    [sim7080g-CuBottom.gbr, sim7080g-CuIn1.gbr, sim7080g-CuIn2.gbr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]
2026-07-22 cross check A0 module is ready for fabrication
    [a0-CuBottom.gbr, a0-CuIn1.gbr, a0-CuIn2.gbr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]
